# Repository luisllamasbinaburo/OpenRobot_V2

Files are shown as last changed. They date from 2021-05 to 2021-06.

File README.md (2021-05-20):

# OpenRobot v2

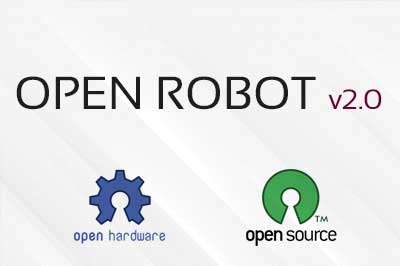
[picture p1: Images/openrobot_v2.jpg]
header


OpenRobot v2 is an Open Hardware PCB based on Arduino Nano, especially designed for teaching technology

Once assembled, you can use make multiple projects and robots without welding, just adding or removing components in the dupont headers.

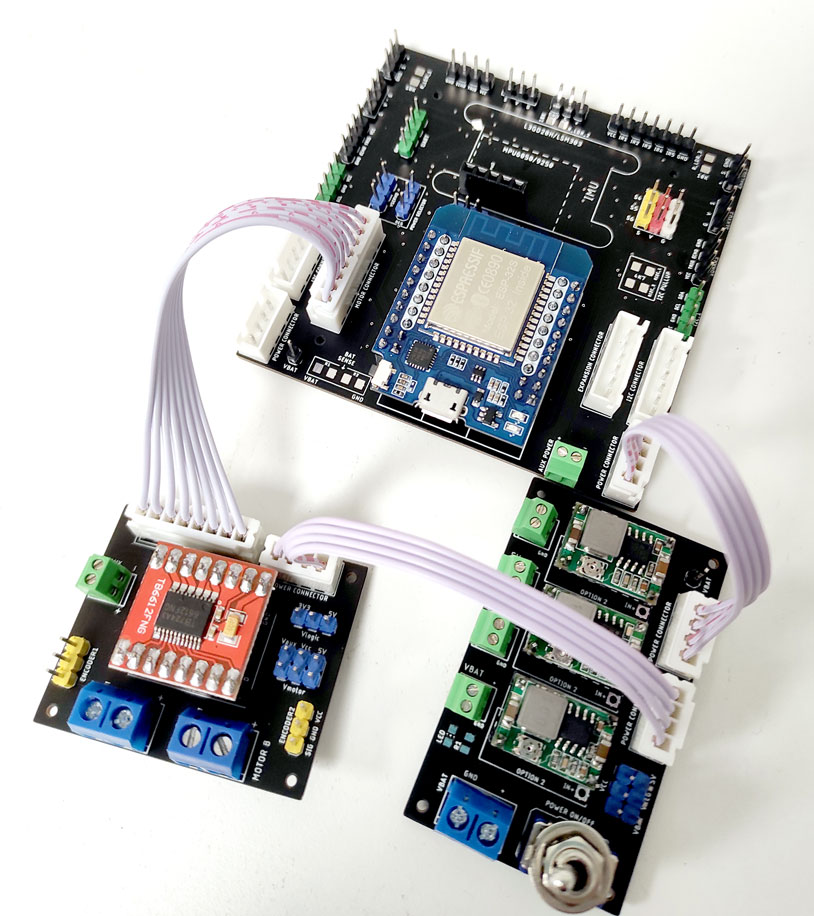
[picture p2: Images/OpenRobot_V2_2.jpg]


OpenRobot v2 is based on a modular design. Just select your main MCU module (Arduino Nano, ESP32, M5Stack...), and the module your project needs (Motors, GPIOs expansion...). Check the Wiki for information about each module.

## What can I make with OpenRobot v2?
Almost any DIY project you can ever imagine! 

Some of them,
- DC Motors Robot, like obstacle avoider (ultrasonic or Sharp), line follower, self-balancing bot...
- Servo Motor Robot, like 2-DOF Tower, 6-DOF Arms...
- Mosfet output for high current proyects (LED, electromagnets, water pumps)
- Bluetooth projects (HC-05/HC-06), like Android or PC communication, beacons...
- WiFi projects (ESP01), like controlling from Web, MQTT datalogger...
- Temperature, pressure, humidity weather station with BME280
- Any other project, thanks to the multiple available outputs!

## Modules
More info about each module in Wiki

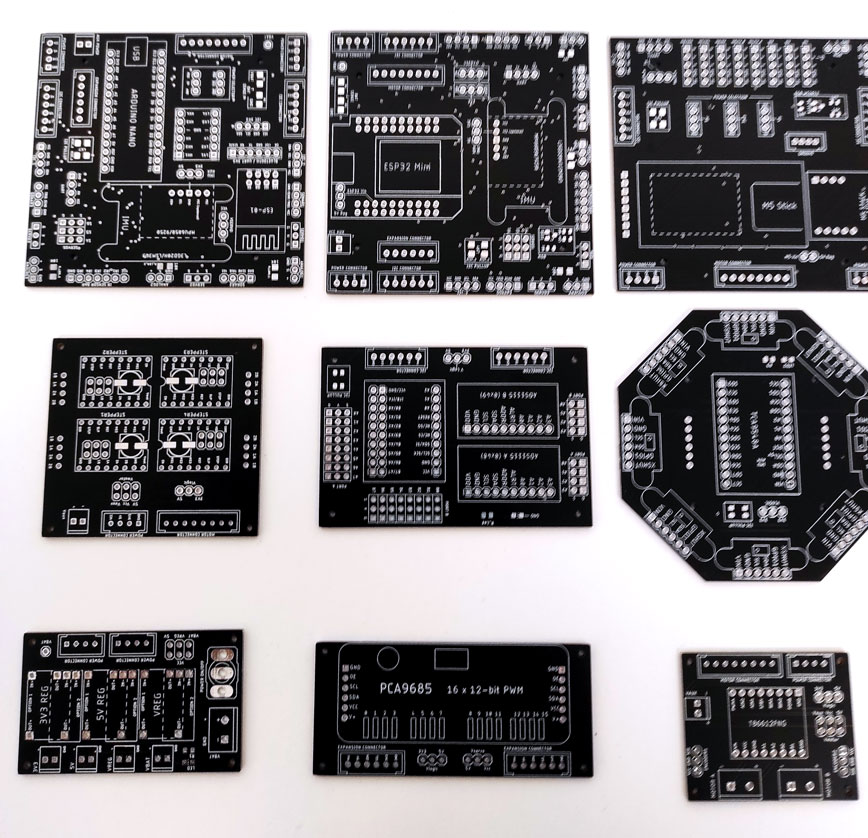
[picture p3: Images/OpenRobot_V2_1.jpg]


#### PowerSource
- DC Converter ([Wiki link](https://github.com/luisllamasbinaburo/OpenRobot_V2/wiki/Module_PowerSource))

#### MCUs
- Arduino Nano ([Wiki link](https://github.com/luisllamasbinaburo/OpenRobot_V2/wiki/Module_MCU_ArduinoNano))
- ESP32 Embed ([Wiki link](https://github.com/luisllamasbinaburo/OpenRobot_V2/wiki/Module_MCU_ESP32Embed))
- M5StickC / M5Stack Atom ([Wiki link](https://github.com/luisllamasbinaburo/OpenRobot_V2/wiki/Module_MCU_M5Stack))

#### Motors
- DC Motors ([Wiki link](https://github.com/luisllamasbinaburo/OpenRobot_V2/wiki/Module_Motor_DC))
- Steppers ([Wiki link](https://github.com/luisllamasbinaburo/OpenRobot_V2/wiki/Module_Motor_Stepper))
- I2C Servos ([Wiki link](https://github.com/luisllamasbinaburo/OpenRobot_V2/wiki/Module_I2C_Servo))

#### Expansions
- I2C GPIO ([Wiki link](https://github.com/luisllamasbinaburo/OpenRobot_V2/wiki/Module_I2C_GPIO))
- I2C TOF ([Wiki link](https://github.com/luisllamasbinaburo/OpenRobot_V2/wiki/Module_I2C_TOF))
- Mosfet ([Wiki link](https://github.com/luisllamasbinaburo/OpenRobot_V2/wiki/Module_Expansion_Mosfet))

## TODO:
- Improve documentation
- Improve code source / utilities (libraries, examples...)

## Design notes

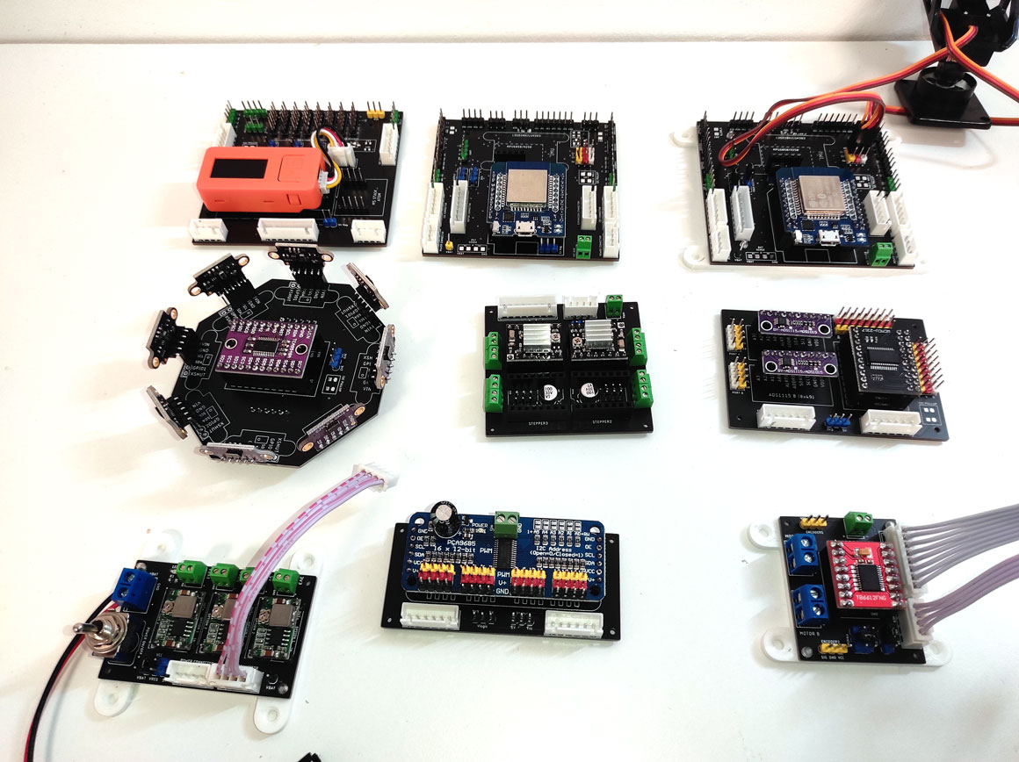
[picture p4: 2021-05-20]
Images/OpenRobot_V2_3.jpg

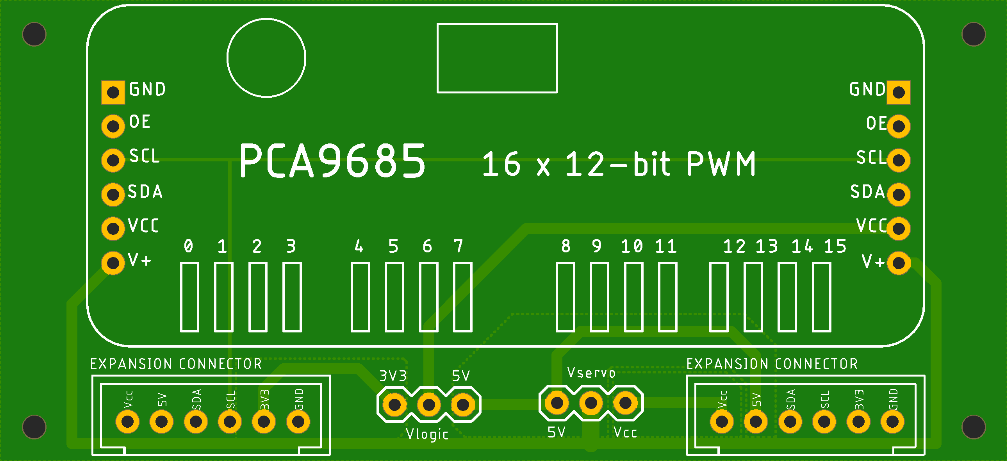
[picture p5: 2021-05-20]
Module_I2C_Servo/Module_I2C_Servo.png

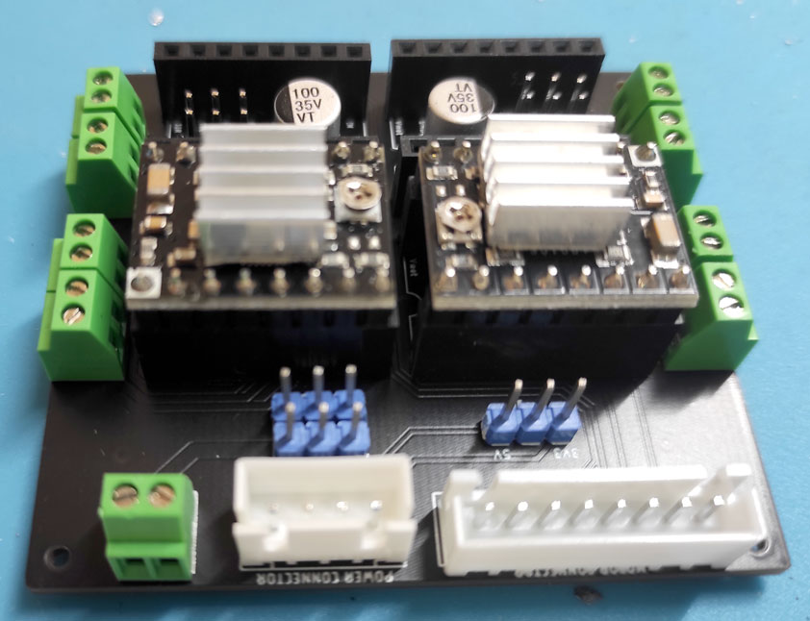
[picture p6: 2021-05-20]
Module_Motor_Stepper/Module_Motor_Stepper.jpg

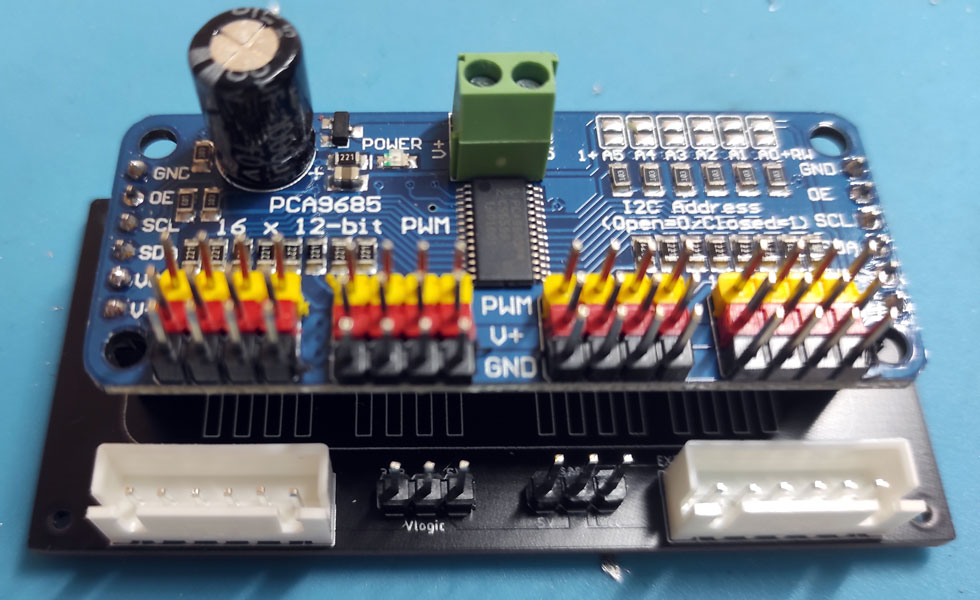
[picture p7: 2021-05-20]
Module_I2C_Servo/Module_I2C_Servo.jpg

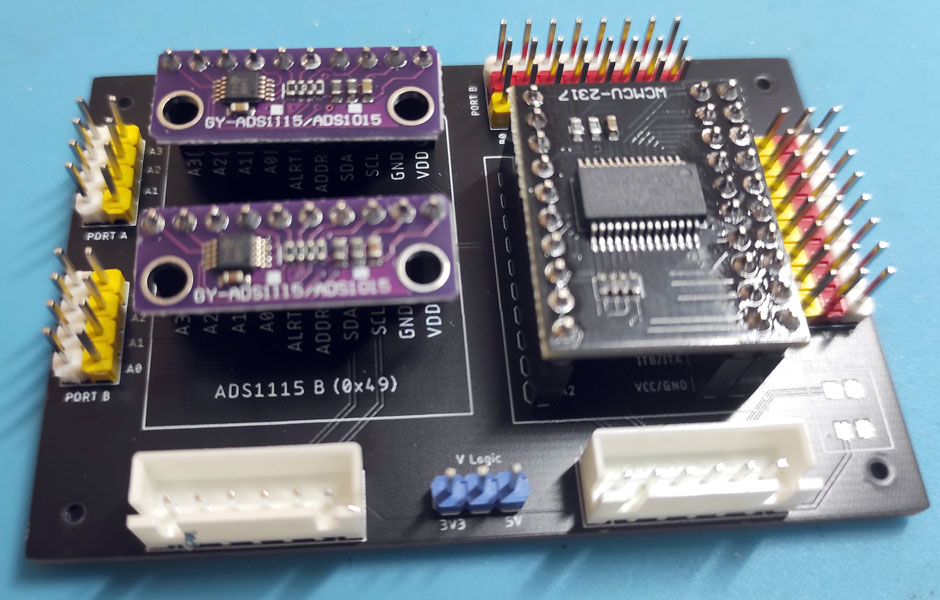
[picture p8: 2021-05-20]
Module_I2C_GPIO/Module_I2C_GPIO.jpg

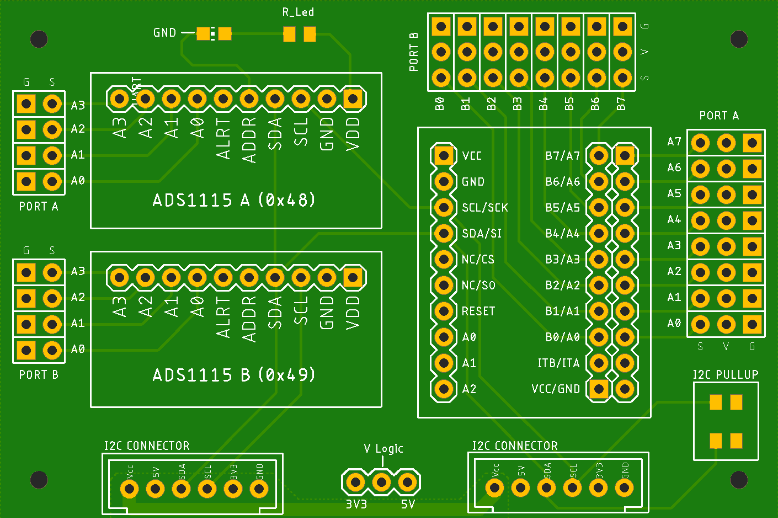
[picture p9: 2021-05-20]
Module_I2C_GPIO/Module_I2C_GPIO.png

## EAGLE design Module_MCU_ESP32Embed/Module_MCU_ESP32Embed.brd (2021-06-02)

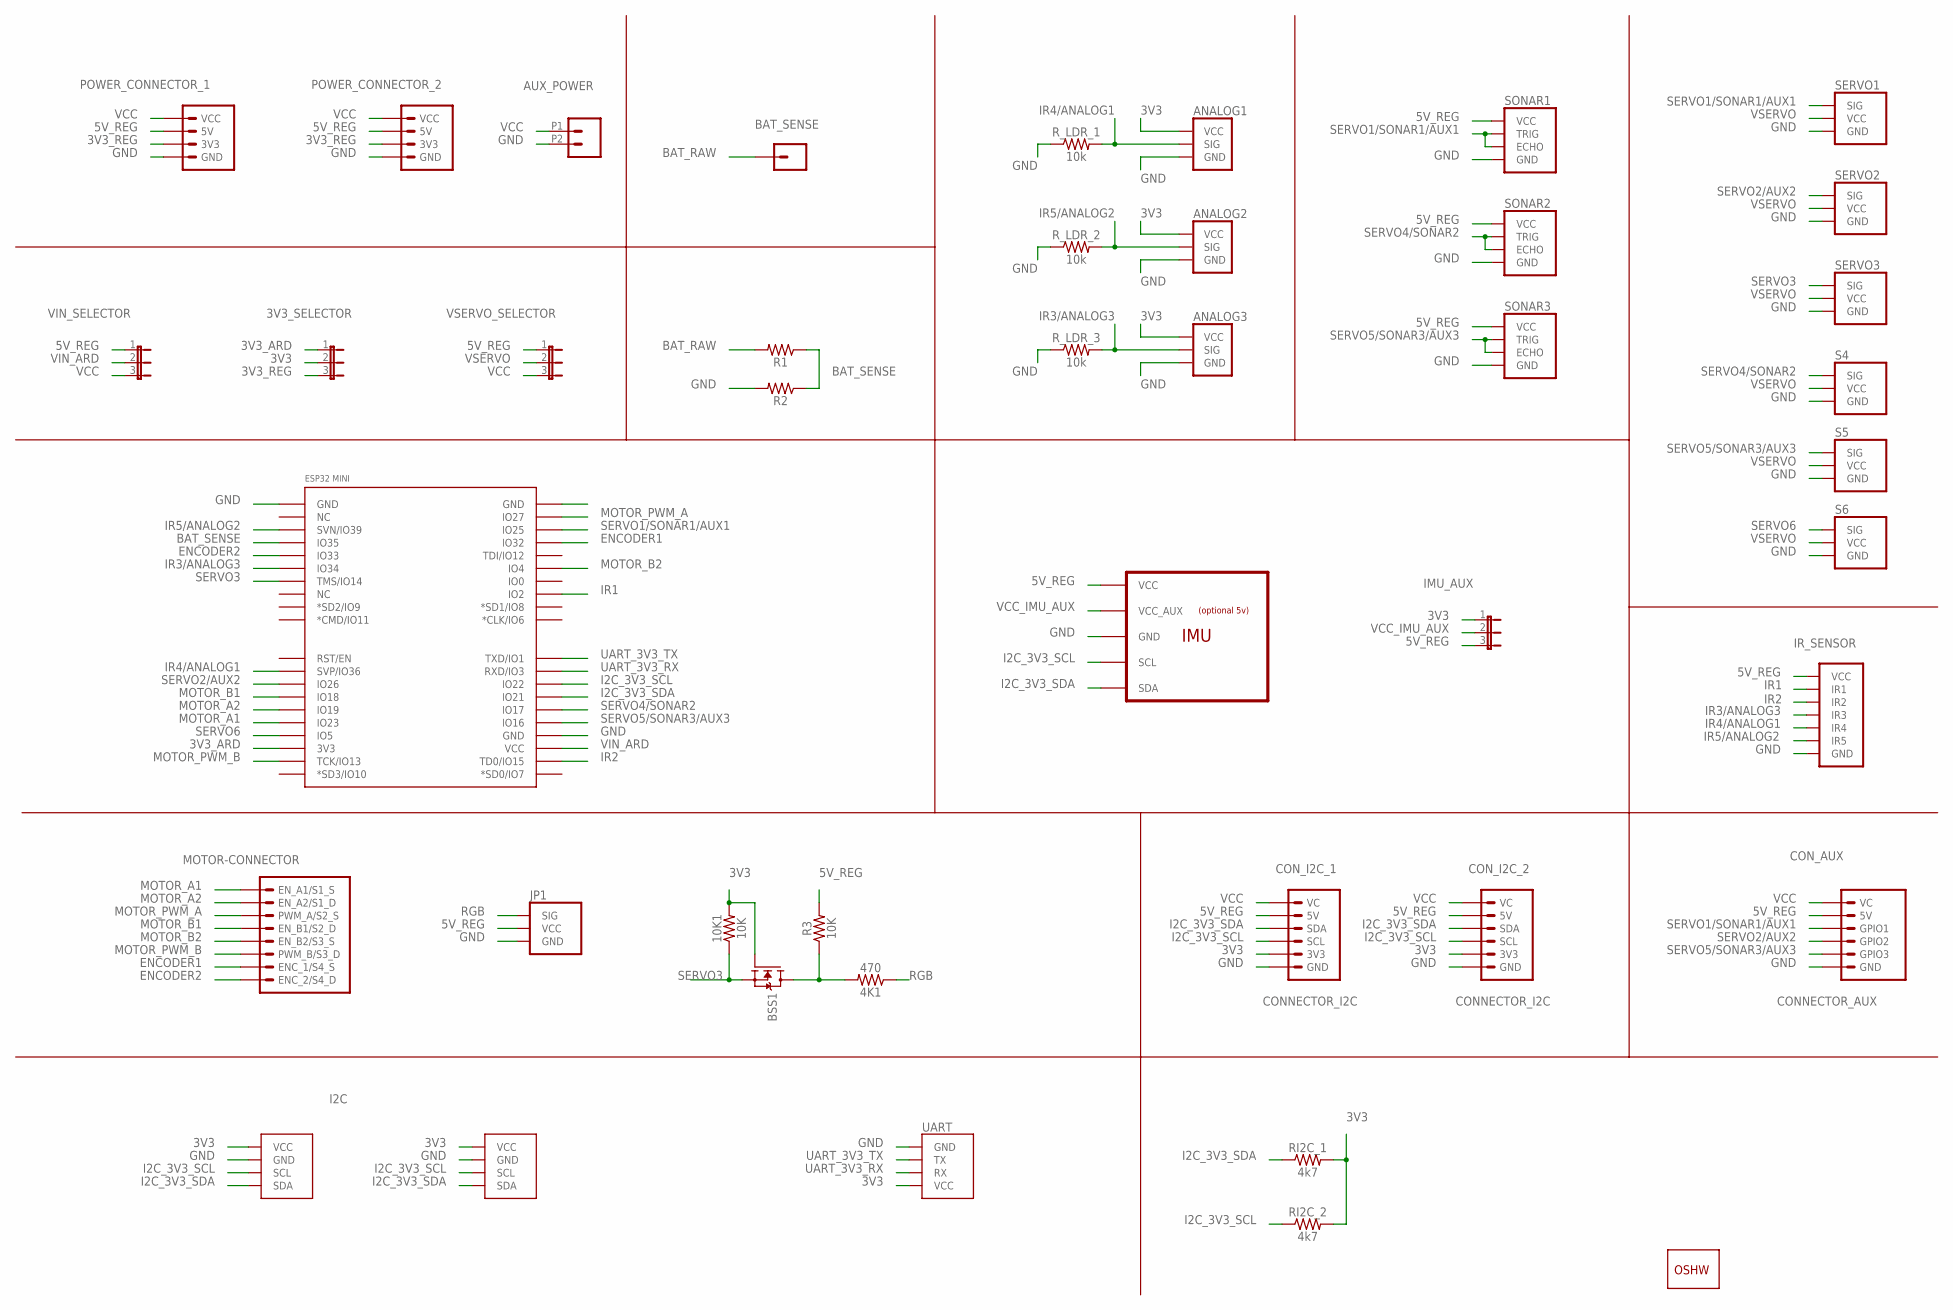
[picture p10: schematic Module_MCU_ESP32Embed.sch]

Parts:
3V3_SELECTOR: JUMPER_3
4K1: 470; 0805
10K1: 10K; 0805
ANALOG1, ANALOG2, ANALOG3: LDR/OCT; LDR
AUX_POWER: CONN_022.54MM_SCREWTERM; 1X02_2.54_SCREWTERM
BAT_SENSE: CONN_01; 1X01
BSS1: MOSFET-N-SOT23; SOT23
CON_AUX: CONNECTOR_AUX
CON_I2C_1, CON_I2C_2: CONNECTOR_I2C
GOLD_ORB_SM1: OSHWLOGO_GOLD_ORB_MED; OSHW1
I2C_1: I2C; I2C_VCC_GND_SCL_SDA
I2C_2: GENERIC_I2CVCC_GND_SCL_SDA; I2C_VCC_GND_SCL_SDA
IMU_AUX: JUMPER_3
IR_SENSOR: IR-5/OCT; IR-5
JP1: SERVOSERVO; SERVO
MOTOR_CONNECTOR: MOTOR-CONNECTOR
POWER_CONNECTOR_1, POWER_CONNECTOR_2: POWER-CONNECTOR
R1, R2: 1206
R3: 10K; 0805
RI2C_1, RI2C_2: 4k7; 1206
R_LDR_1, R_LDR_2, R_LDR_3: 10k; 1206
S4, S5, S6: SERVOSERVO; SERVO
SERVO1, SERVO2, SERVO3: SERVOSERVO; SERVO
SONAR1, SONAR2, SONAR3: ULTRASONIC/OCT; ULTRASONIC
U1: IMU_6/9/10DOFMPU6050; IMU_6/9/10DOF
U$5: ESP32-WEMOS
UART: UART; GENERIC_UART
VIN_SELECTOR: JUMPER_3
VSERVO_SELECTOR: JUMPER_3

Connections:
3V3: 3V3_SELECTOR.2, 10K1.2, ANALOG1.VCC, ANALOG2.VCC, ANALOG3.VCC, BSS1.1 (G), CON_I2C_1.3V3, CON_I2C_2.3V3, I2C_1.VCC, I2C_2.VCC, IMU_AUX.1, RI2C_1.2, RI2C_2.2, UART.VCC
3V3_ARD: 3V3_SELECTOR.1, U$5.3V3
3V3_REG: 3V3_SELECTOR.3, POWER_CONNECTOR_1.3V3, POWER_CONNECTOR_2.3V3
5V_REG: CON_AUX.5V, CON_I2C_1.5V, CON_I2C_2.5V, IMU_AUX.3, IR_SENSOR.VCC, JP1.VCC, POWER_CONNECTOR_1.5V, POWER_CONNECTOR_2.5V, R3.2, SONAR1.VCC, SONAR2.VCC, SONAR3.VCC, U1.VCC, VIN_SELECTOR.1, VSERVO_SELECTOR.1
BAT_RAW: BAT_SENSE.1, R1.2
BAT_SENSE: R1.1, R2.1, U$5.IO35
ENCODER1: MOTOR_CONNECTOR.ENC_1/S4_S, U$5.IO32
ENCODER2: MOTOR_CONNECTOR.ENC_2/S4_D, U$5.IO33
GND: ANALOG1.GND, ANALOG2.GND, ANALOG3.GND, AUX_POWER.P2 (2), CON_AUX.GND, CON_I2C_1.GND, CON_I2C_2.GND, I2C_1.GND, I2C_2.GND, IR_SENSOR.GND, JP1.GND, POWER_CONNECTOR_1.GND, POWER_CONNECTOR_2.GND, R2.2, R_LDR_1.1, R_LDR_2.1, R_LDR_3.1, S4.GND, S5.GND, S6.GND, SERVO1.GND, SERVO2.GND, SERVO3.GND, SONAR1.GND, SONAR2.GND, SONAR3.GND, U1.GND, U$5.GND@1 (GND), U$5.GND@3 (GND), UART.GND
I2C_3V3_SCL: CON_I2C_1.SCL, CON_I2C_2.SCL, I2C_1.SCL, I2C_2.SCL, RI2C_2.1, U1.SCL, U$5.IO22
I2C_3V3_SDA: CON_I2C_1.SDA, CON_I2C_2.SDA, I2C_1.SDA, I2C_2.SDA, RI2C_1.1, U1.SDA, U$5.IO21
IR1: IR_SENSOR.1 (IR1), U$5.IO2
IR2: IR_SENSOR.2 (IR2), U$5.TD0/IO15
IR3/ANALOG3: ANALOG3.SIG, IR_SENSOR.3 (IR3), R_LDR_3.2, U$5.IO34
IR4/ANALOG1: ANALOG1.SIG, IR_SENSOR.4 (IR4), R_LDR_1.2, U$5.SVP/IO36
IR5/ANALOG2: ANALOG2.SIG, IR_SENSOR.5 (IR5), R_LDR_2.2, U$5.SVN/IO39
MOTOR_A1: MOTOR_CONNECTOR.EN_A1/S1_S, U$5.IO23
MOTOR_A2: MOTOR_CONNECTOR.EN_A2/S1_D, U$5.IO19
MOTOR_B1: MOTOR_CONNECTOR.EN_B1/S2_D, U$5.IO18
MOTOR_B2: MOTOR_CONNECTOR.EN_B2/S3_S, U$5.IO4
MOTOR_PWM_A: MOTOR_CONNECTOR.PWM_A/S2_S, U$5.IO27
MOTOR_PWM_B: MOTOR_CONNECTOR.PWM_B/S3_D, U$5.TCK/IO13
unnamed: 4K1.2, BSS1.3 (D), R3.1
RGB: 4K1.1, JP1.SIG
SERVO1/SONAR1/AUX1: CON_AUX.GPIO1, SERVO1.SIG, SONAR1.ECHO, SONAR1.TRIG, U$5.IO25
SERVO2/AUX2: CON_AUX.GPIO2, SERVO2.SIG, U$5.IO26
SERVO3: 10K1.1, BSS1.2 (S), SERVO3.SIG, U$5.TMS/IO14
SERVO4/SONAR2: S4.SIG, SONAR2.ECHO, SONAR2.TRIG, U$5.IO17
SERVO5/SONAR3/AUX3: CON_AUX.GPIO3, S5.SIG, SONAR3.ECHO, SONAR3.TRIG, U$5.IO16
SERVO6: S6.SIG, U$5.IO5
UART_3V3_RX: U$5.RXD/IO3, UART.RX
UART_3V3_TX: U$5.TXD/IO1, UART.TX
VCC: AUX_POWER.P1 (1), CON_AUX.VC, CON_I2C_1.VC, CON_I2C_2.VC, POWER_CONNECTOR_1.VCC, POWER_CONNECTOR_2.VCC, VIN_SELECTOR.3, VSERVO_SELECTOR.3
VCC_IMU_AUX: IMU_AUX.2, U1.VCC_AUX
VIN_ARD: U$5.VCC, VIN_SELECTOR.2
VSERVO: S4.VCC, S5.VCC, S6.VCC, SERVO1.VCC, SERVO2.VCC, SERVO3.VCC, VSERVO_SELECTOR.2

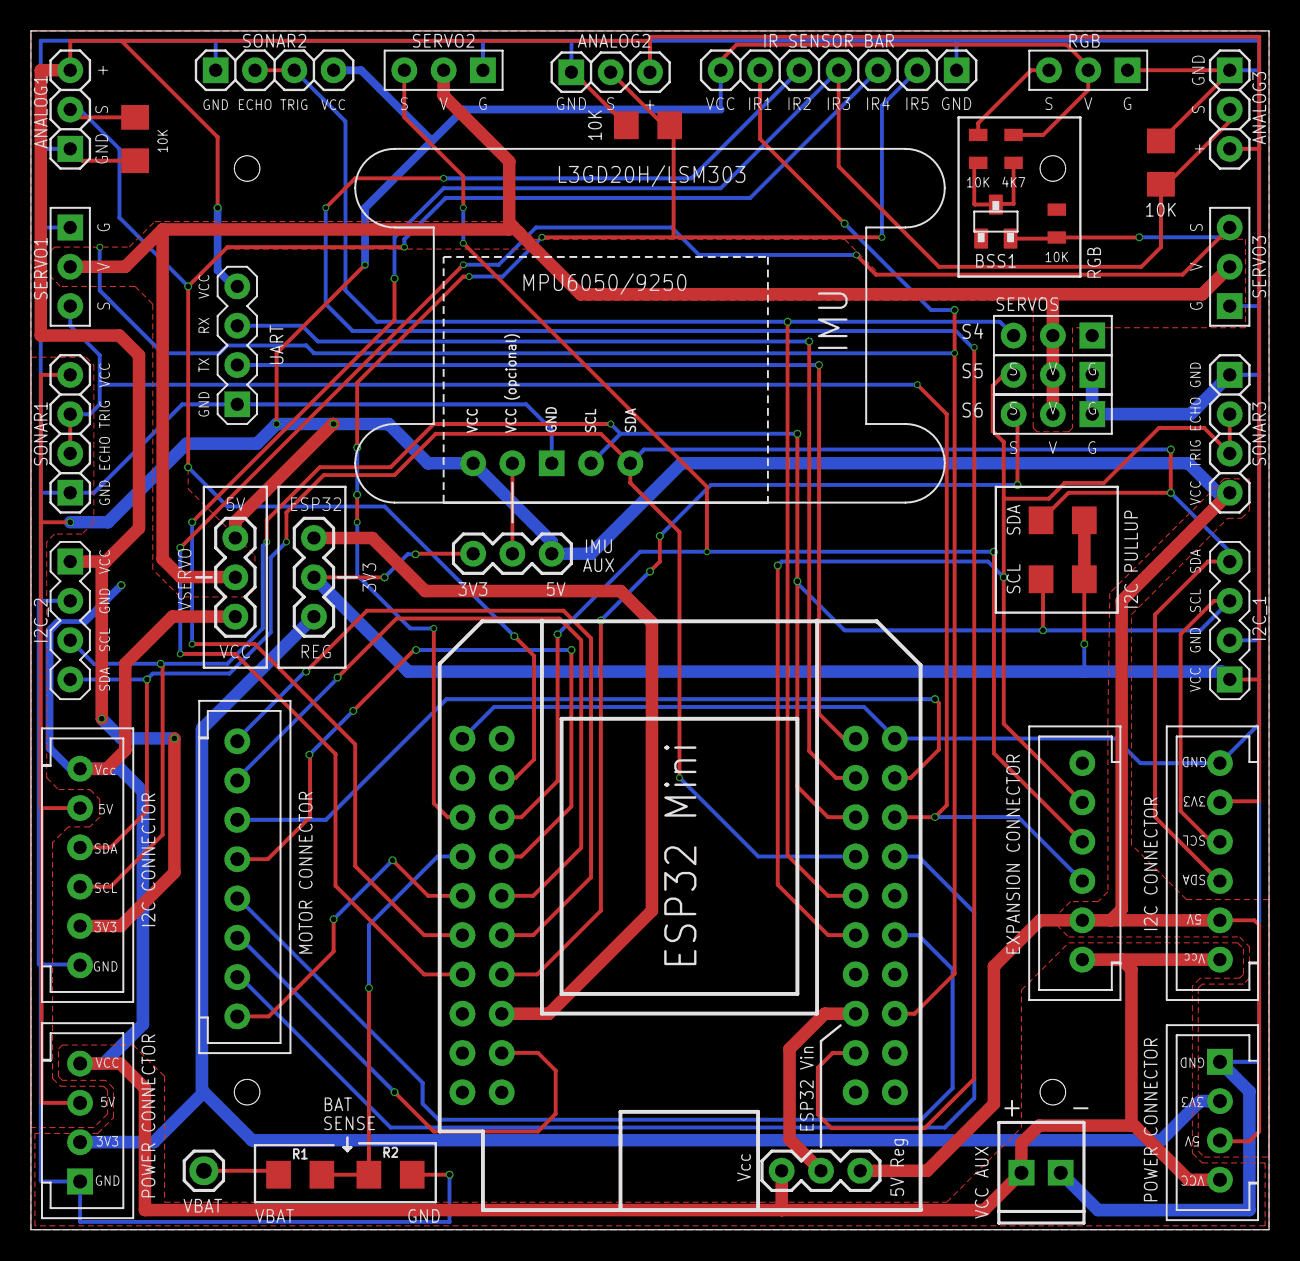
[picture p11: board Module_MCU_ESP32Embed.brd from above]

Board: 2 copper layers, 80.0 x 77.5 mm, 43 parts (1 on the bottom side), 36 nets.

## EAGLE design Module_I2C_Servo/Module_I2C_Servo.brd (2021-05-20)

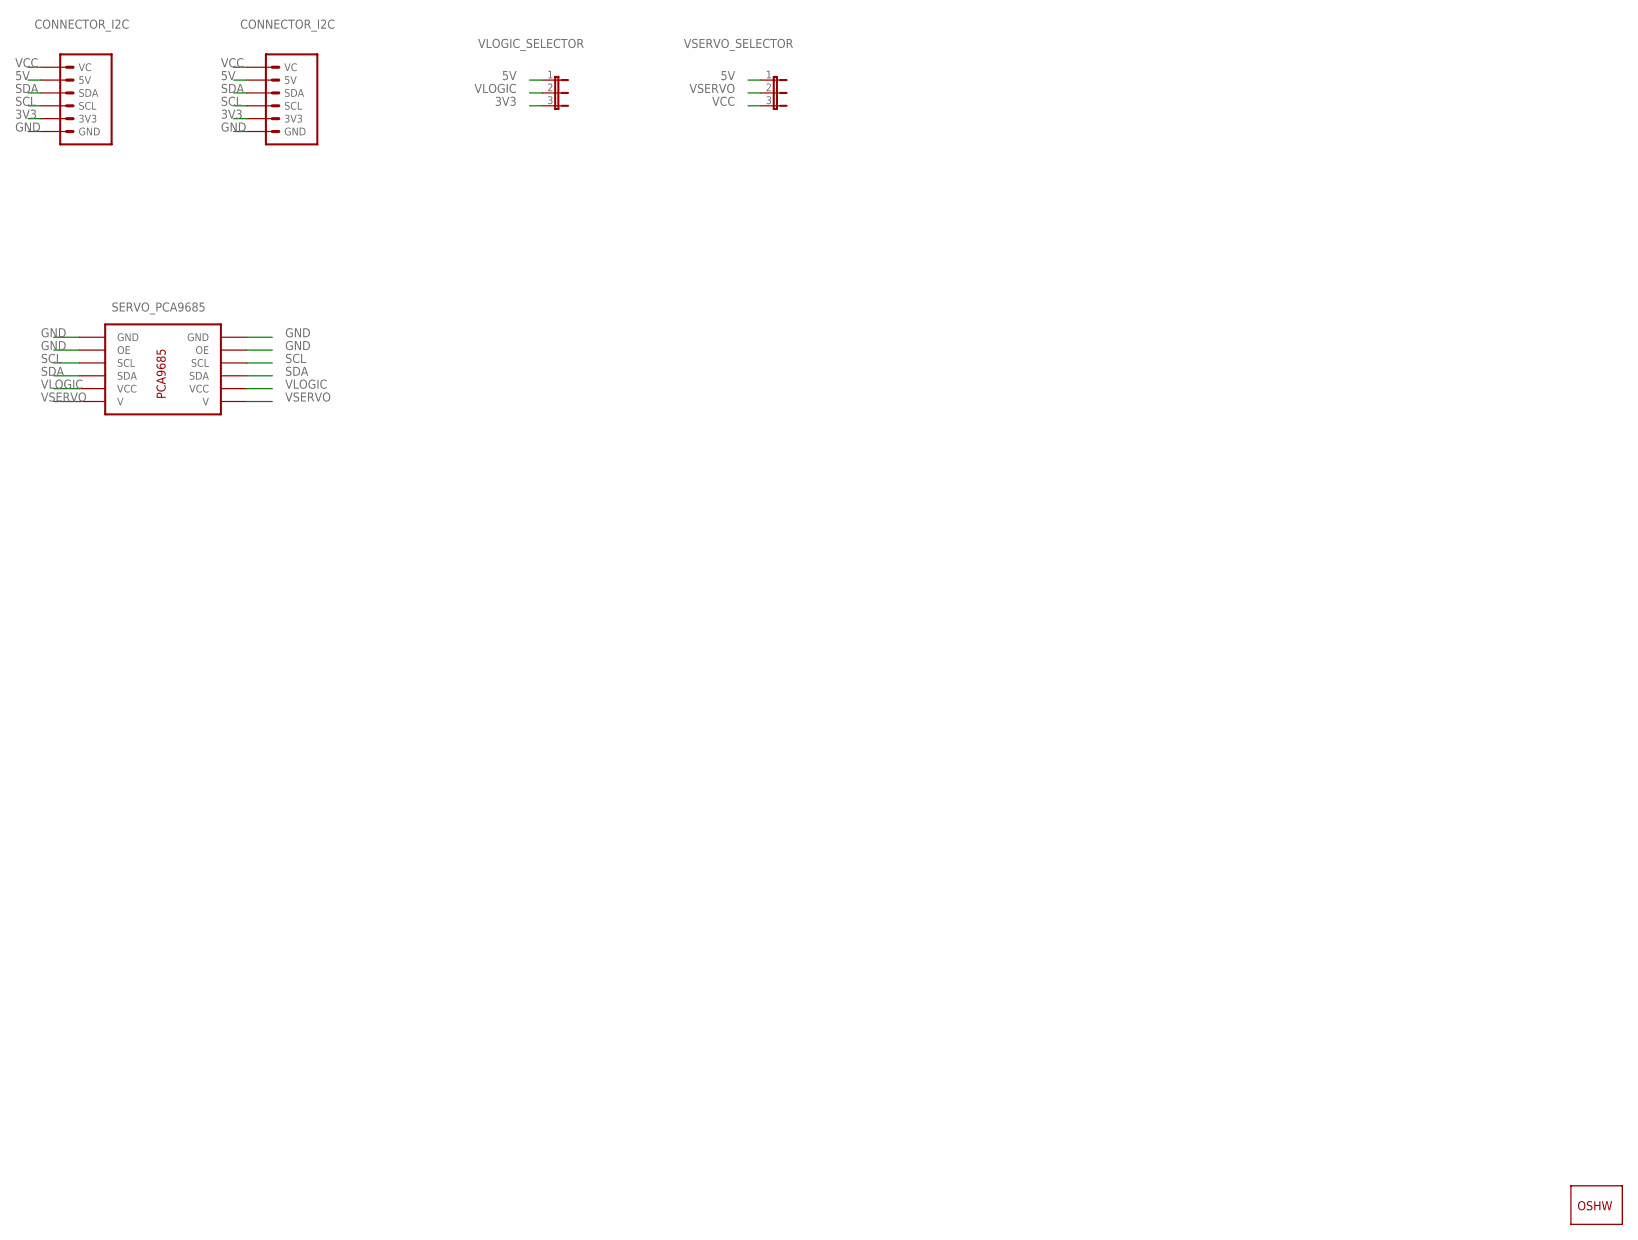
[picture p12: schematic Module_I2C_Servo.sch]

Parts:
GOLD_ORB_SM1: OSHWLOGO_GOLD_ORB_MED; OSHW1
U$2: SERVO_PCA9685
U$3, U$4: CONNECTOR_I2C
VLOGIC_SELECTOR: JUMPER_3
VSERVO_SELECTOR: JUMPER_3

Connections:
3V3: U$3.3V3, U$4.3V3, VLOGIC_SELECTOR.3
5V: U$3.5V, U$4.5V, VLOGIC_SELECTOR.1, VSERVO_SELECTOR.1
GND: U$2.GND@0 (GND), U$2.GND@1 (GND), U$2.OE@0 (OE), U$2.OE@1 (OE), U$3.GND, U$4.GND
SCL: U$2.SCL@0 (SCL), U$2.SCL@1 (SCL), U$3.SCL, U$4.SCL
SDA: U$2.SDA@0 (SDA), U$2.SDA@1 (SDA), U$3.SDA, U$4.SDA
VCC: U$3.VC, U$4.VC, VSERVO_SELECTOR.3
VLOGIC: U$2.VCC@0 (VCC), U$2.VCC@1 (VCC), VLOGIC_SELECTOR.2
VSERVO: U$2.VSERVO@0 (V), U$2.VSERVO@1 (V), VSERVO_SELECTOR.2

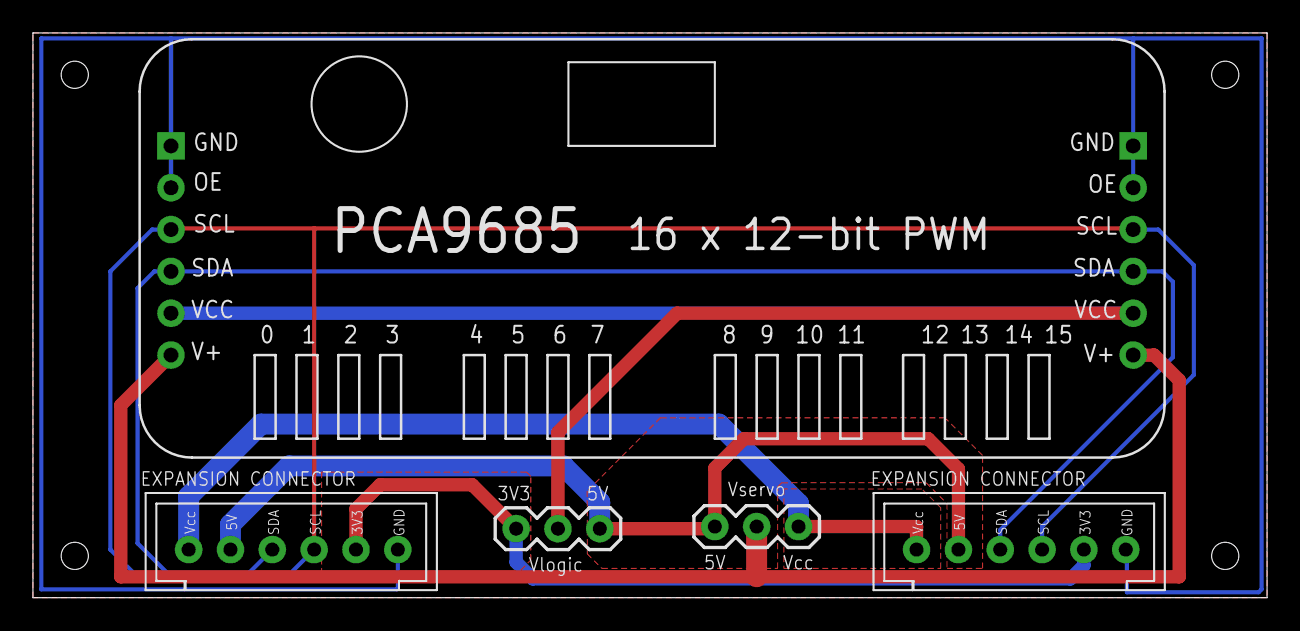
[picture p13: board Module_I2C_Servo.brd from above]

Board: 2 copper layers, 74.9 x 34.3 mm, 6 parts (1 on the bottom side), 8 nets.

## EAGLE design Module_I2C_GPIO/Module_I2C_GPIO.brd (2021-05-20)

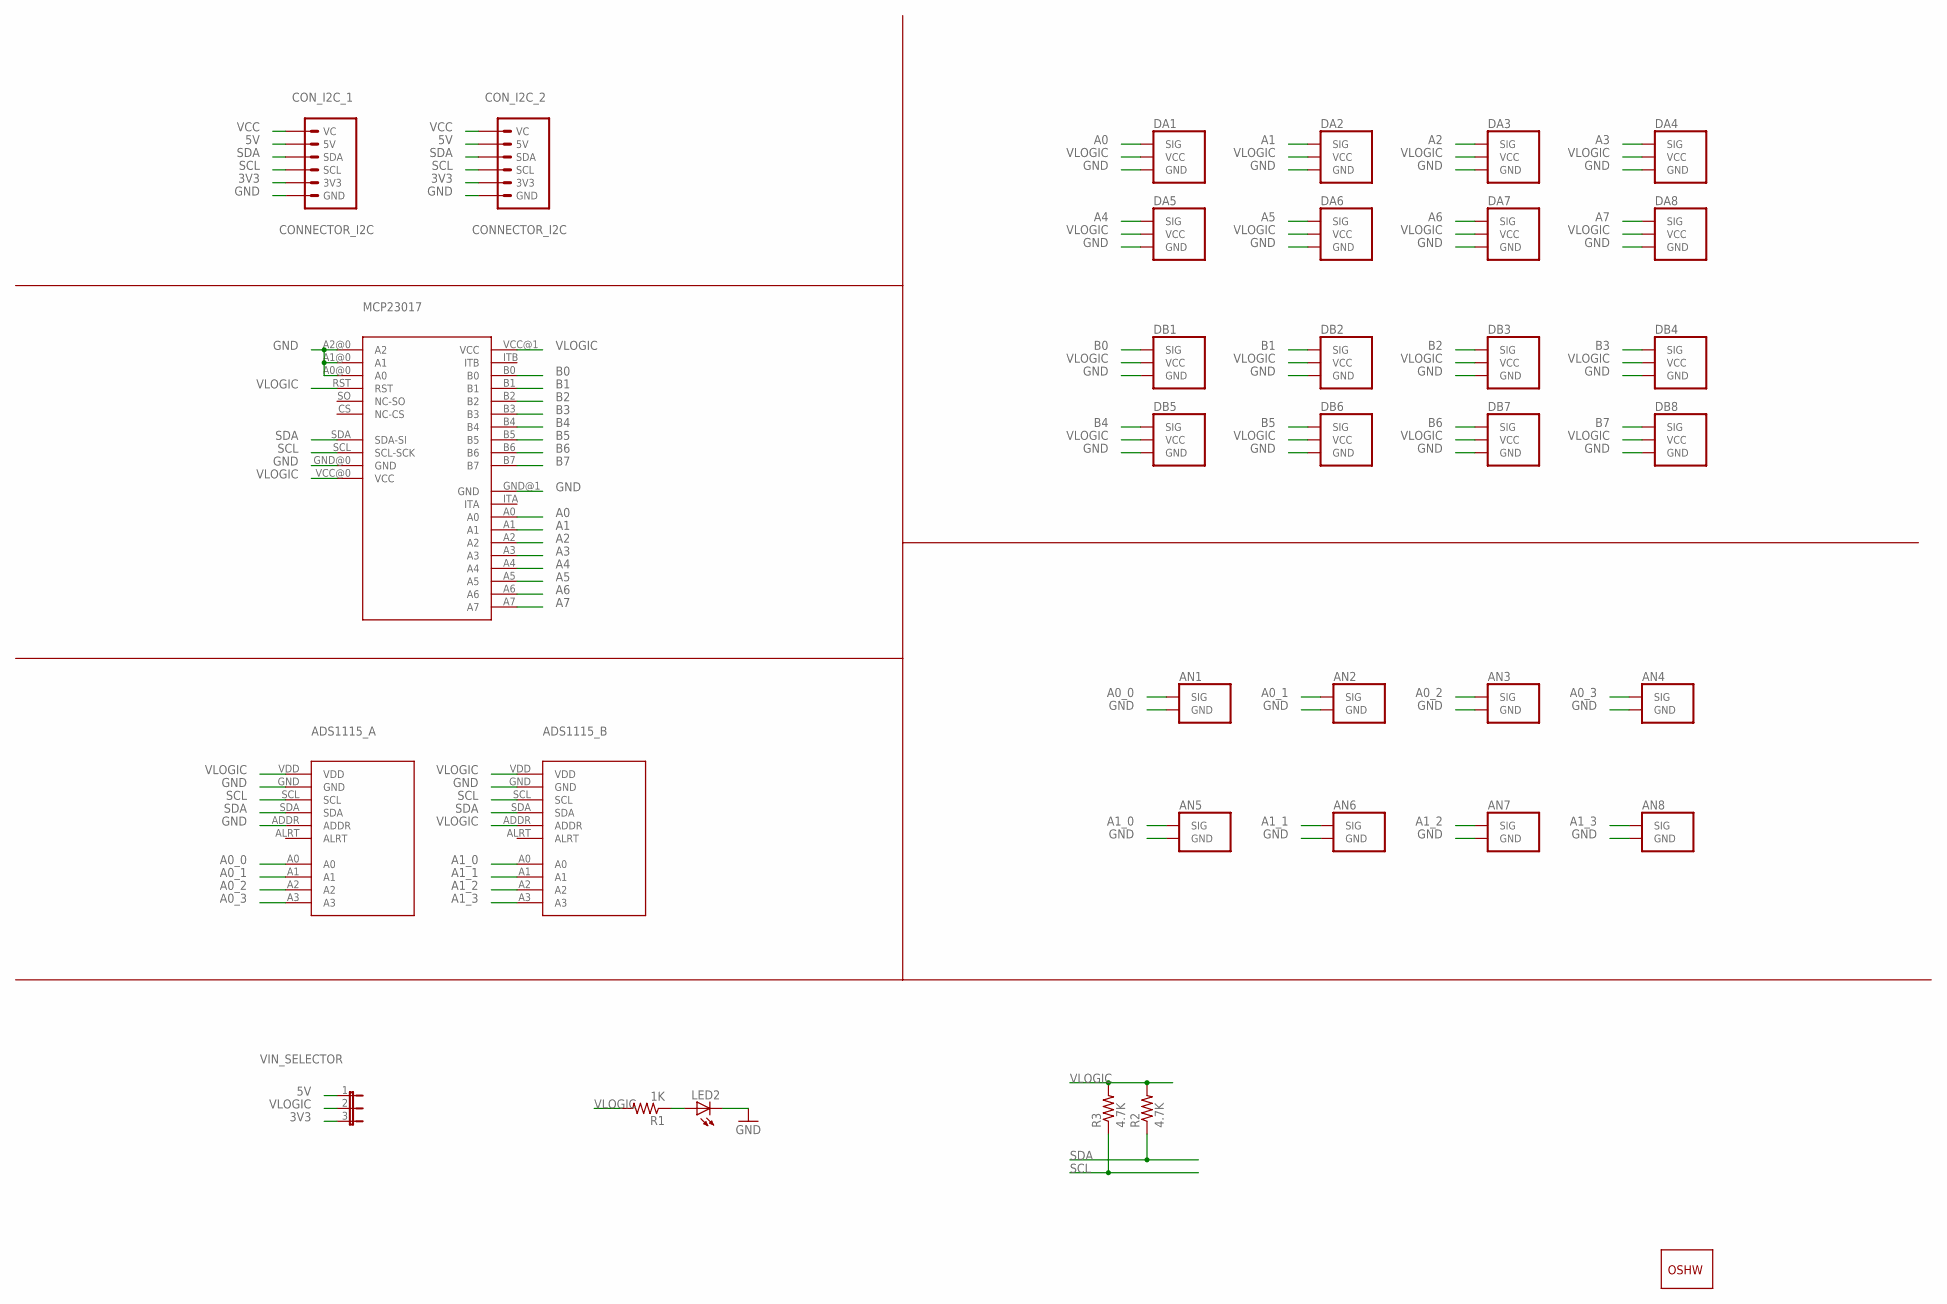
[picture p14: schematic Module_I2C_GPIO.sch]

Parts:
ADS1115_A, ADS1115_B: ADC-4CH-ADS1115
AN1, AN2, AN3, AN4, AN5, AN6, AN7, AN8: SERVO_2
CON_I2C_1, CON_I2C_2: CONNECTOR_I2C
DA1, DA2, DA3, DA4, DA5, DA6, DA7, DA8: SERVOSERVO; SERVO
DB1, DB2, DB3, DB4, DB5, DB6, DB7, DB8: SERVOSERVO; SERVO
GOLD_ORB_SM1: OSHWLOGO_GOLD_ORB_MED; OSHW1
LED2: LEDCHIP-LED0805; CHIP-LED0805
MCP23017: GPIO-I2C-MCP23017
R1: 1K; R0805
R2, R3: 4.7K; R0805
VIN_SELECTOR: JUMPER_3

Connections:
3V3: CON_I2C_1.3V3, CON_I2C_2.3V3, VIN_SELECTOR.3
5V: CON_I2C_1.5V, CON_I2C_2.5V, VIN_SELECTOR.1
A0: DA1.SIG, MCP23017.A0
A0_0: ADS1115_A.A0, AN1.SIG
A0_1: ADS1115_A.A1, AN2.SIG
A0_2: ADS1115_A.A2, AN3.SIG
A0_3: ADS1115_A.A3, AN4.SIG
A1: DA2.SIG, MCP23017.A1
A1_0: ADS1115_B.A0, AN5.SIG
A1_1: ADS1115_B.A1, AN6.SIG
A1_2: ADS1115_B.A2, AN7.SIG
A1_3: ADS1115_B.A3, AN8.SIG
A2: DA3.SIG, MCP23017.A2
A3: DA4.SIG, MCP23017.A3
A4: DA5.SIG, MCP23017.A4
A5: DA6.SIG, MCP23017.A5
A6: DA7.SIG, MCP23017.A6
A7: DA8.SIG, MCP23017.A7
B0: DB1.SIG, MCP23017.B0
B1: DB2.SIG, MCP23017.B1
B2: DB3.SIG, MCP23017.B2
B3: DB4.SIG, MCP23017.B3
B4: DB5.SIG, MCP23017.B4
B5: DB6.SIG, MCP23017.B5
B6: DB7.SIG, MCP23017.B6
B7: DB8.SIG, MCP23017.B7
GND: ADS1115_A.ADDR, ADS1115_A.GND, ADS1115_B.GND, AN1.GND, AN2.GND, AN3.GND, AN4.GND, AN5.GND, AN6.GND, AN7.GND, AN8.GND, CON_I2C_1.GND, CON_I2C_2.GND, DA1.GND, DA2.GND, DA3.GND, DA4.GND, DA5.GND, DA6.GND, DA7.GND, DA8.GND, DB1.GND, DB2.GND, DB3.GND, DB4.GND, DB5.GND, DB6.GND, DB7.GND, DB8.GND, LED2.C, MCP23017.A0@0 (A0), MCP23017.A1@0 (A1), MCP23017.A2@0 (A2), MCP23017.GND@0 (GND), MCP23017.GND@1 (GND)
unnamed: LED2.A, R1.1
SCL: ADS1115_A.SCL, ADS1115_B.SCL, CON_I2C_1.SCL, CON_I2C_2.SCL, MCP23017.SCL (SCL-SCK), R3.1
SDA: ADS1115_A.SDA, ADS1115_B.SDA, CON_I2C_1.SDA, CON_I2C_2.SDA, MCP23017.SDA (SDA-SI), R2.1
VCC: CON_I2C_1.VC, CON_I2C_2.VC
VLOGIC: ADS1115_A.VDD, ADS1115_B.ADDR, ADS1115_B.VDD, DA1.VCC, DA2.VCC, DA3.VCC, DA4.VCC, DA5.VCC, DA6.VCC, DA7.VCC, DA8.VCC, DB1.VCC, DB2.VCC, DB3.VCC, DB4.VCC, DB5.VCC, DB6.VCC, DB7.VCC, DB8.VCC, MCP23017.RST, MCP23017.VCC@0 (VCC), MCP23017.VCC@1 (VCC), R1.2, R2.2, R3.2, VIN_SELECTOR.2

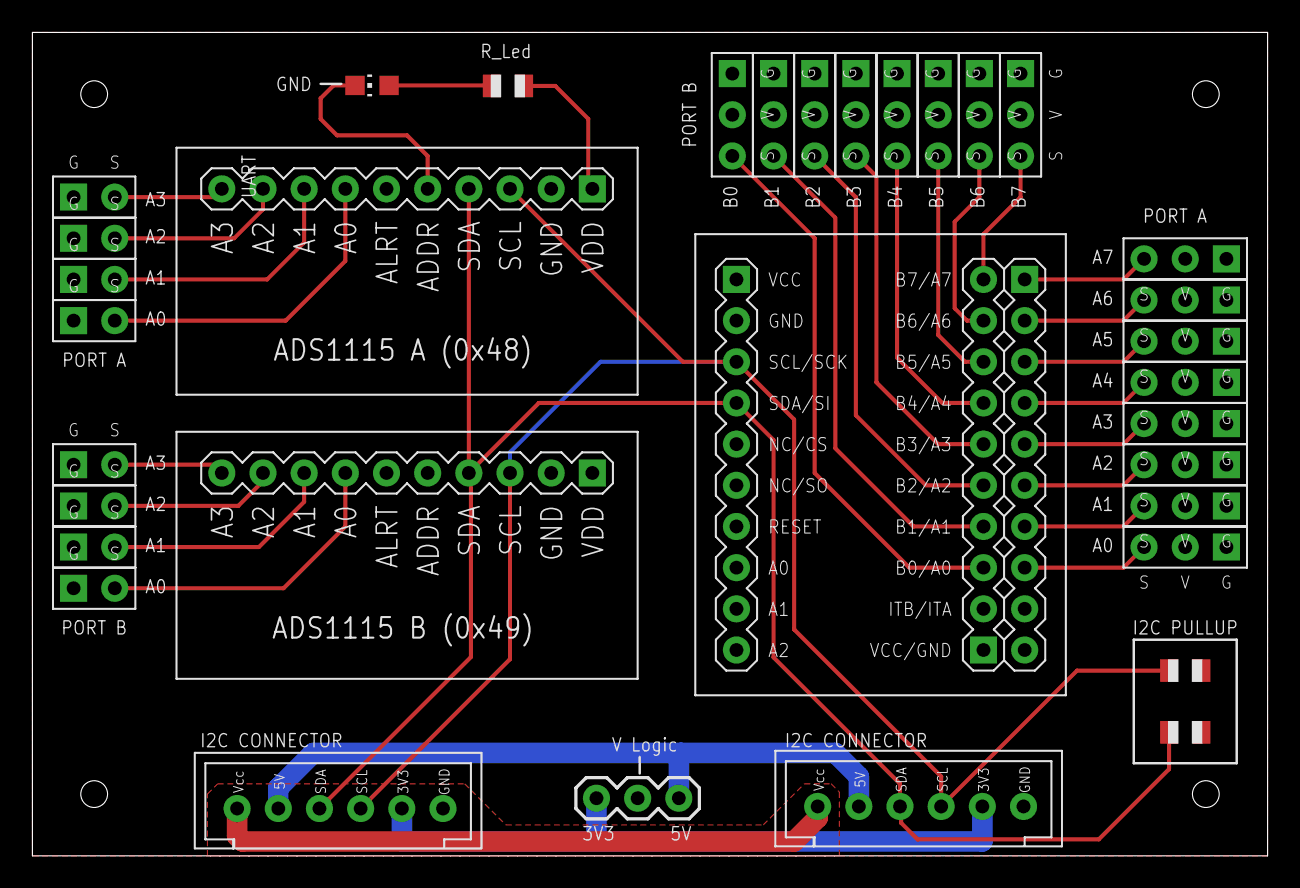
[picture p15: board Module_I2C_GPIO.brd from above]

Board: 2 copper layers, 76.2 x 50.8 mm, 35 parts (1 on the bottom side), 32 nets.

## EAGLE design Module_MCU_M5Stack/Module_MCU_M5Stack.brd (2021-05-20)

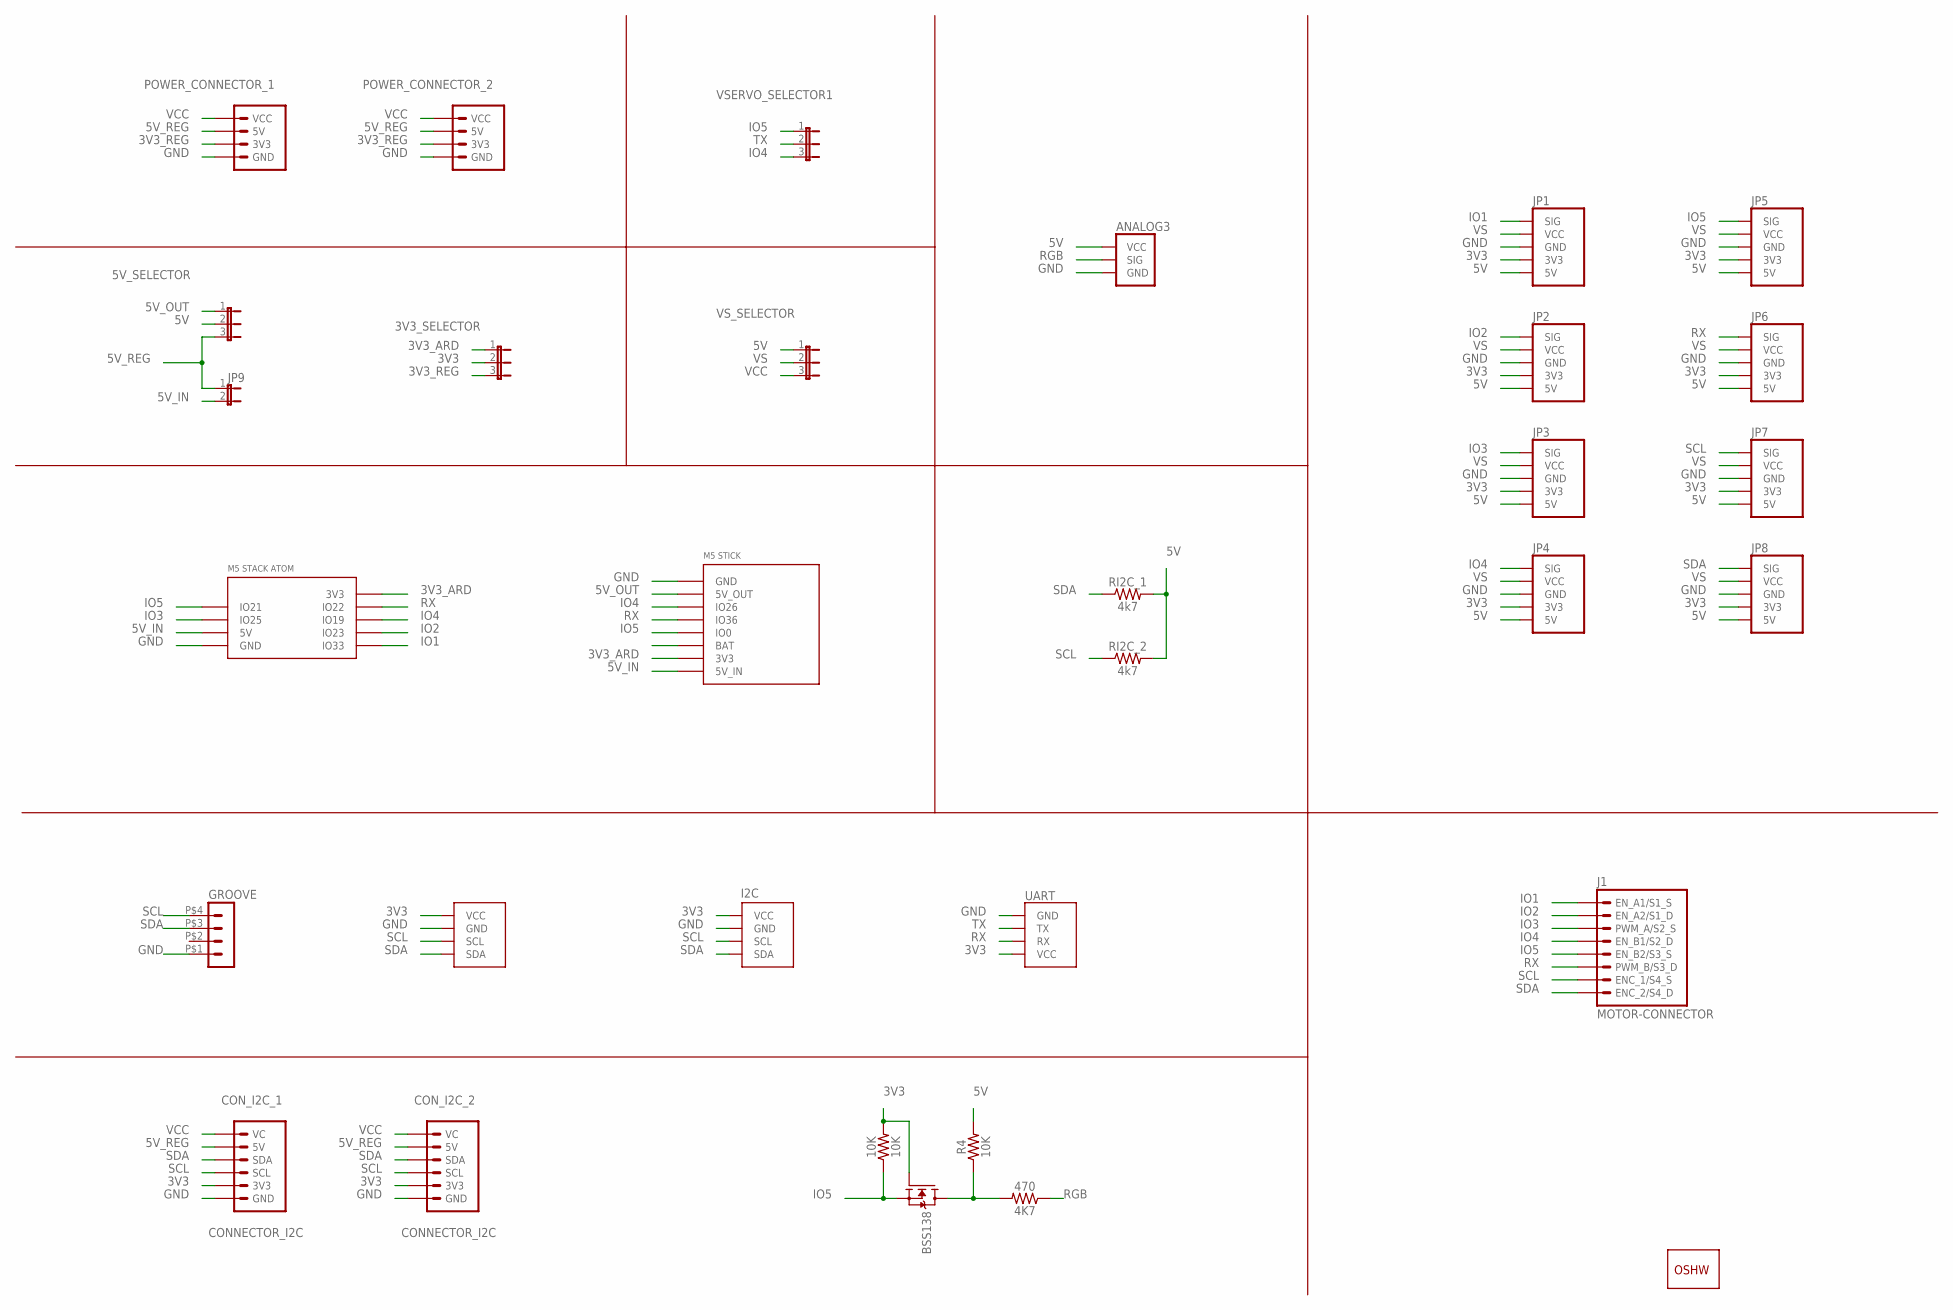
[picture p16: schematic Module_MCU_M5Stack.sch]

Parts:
3V3_SELECTOR, 5V_SELECTOR: JUMPER_3
4K7: 470; 0805
10K: 10K; 0805
ANALOG3: LDR/OCT; LDR
BSS138: MOSFET-N-SOT23; SOT23
CON_I2C_1, CON_I2C_2: CONNECTOR_I2C
GOLD_ORB_SM1: OSHWLOGO_GOLD_ORB_MED; OSHW1
GROOVE: GROOVE
I2C_1: I2C; I2C_VCC_GND_SCL_SDA
I2C_2: GENERIC_I2CVCC_GND_SCL_SDA; I2C_VCC_GND_SCL_SDA
J1: MOTOR-CONNECTOR
JP1, JP2, JP3, JP4, JP5, JP6, JP7, JP8: SERVO_5
JP9: JUMPER_2PTH; JUMPER_2
POWER_CONNECTOR_1, POWER_CONNECTOR_2: POWER-CONNECTOR
R4: 10K; 0805
RI2C_1, RI2C_2: 4k7; 1206
U$1: M5-STACK-ATOM
U$2: M5-STICK
UART: UART; GENERIC_UART
VSERVO_SELECTOR1: JUMPER_3
VS_SELECTOR: JUMPER_3

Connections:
3V3: 3V3_SELECTOR.2, 10K.2, BSS138.1 (G), CON_I2C_1.3V3, CON_I2C_2.3V3, I2C_1.VCC, I2C_2.VCC, JP1.3V3, JP2.3V3, JP3.3V3, JP4.3V3, JP5.3V3, JP6.3V3, JP7.3V3, JP8.3V3, UART.VCC
3V3_ARD: 3V3_SELECTOR.1, U$1.3V3, U$2.3V3
3V3_REG: 3V3_SELECTOR.3, POWER_CONNECTOR_1.3V3, POWER_CONNECTOR_2.3V3
5V: 5V_SELECTOR.2, ANALOG3.VCC, JP1.5V, JP2.5V, JP3.5V, JP4.5V, JP5.5V, JP6.5V, JP7.5V, JP8.5V, R4.2, RI2C_1.2, RI2C_2.2, VS_SELECTOR.1
5V_IN: JP9.2, U$1.5V, U$2.5V_IN
5V_OUT: 5V_SELECTOR.1, U$2.5V_OUT
5V_REG: 5V_SELECTOR.3, CON_I2C_1.5V, CON_I2C_2.5V, JP9.1, POWER_CONNECTOR_1.5V, POWER_CONNECTOR_2.5V
GND: ANALOG3.GND, CON_I2C_1.GND, CON_I2C_2.GND, GROOVE.P$1 (1), I2C_1.GND, I2C_2.GND, JP1.GND, JP2.GND, JP3.GND, JP4.GND, JP5.GND, JP6.GND, JP7.GND, JP8.GND, POWER_CONNECTOR_1.GND, POWER_CONNECTOR_2.GND, U$1.GND, U$2.GND, UART.GND
IO1: J1.EN_A1/S1_S, JP1.SIG, U$1.IO33
IO2: J1.EN_A2/S1_D, JP2.SIG, U$1.IO23
IO3: J1.PWM_A/S2_S, JP3.SIG, U$1.IO25
IO4: J1.EN_B1/S2_D, JP4.SIG, U$1.IO19, U$2.IO26, VSERVO_SELECTOR1.3
IO5: 10K.1, BSS138.2 (S), J1.EN_B2/S3_S, JP5.SIG, U$1.IO21, U$2.IO0, VSERVO_SELECTOR1.1
unnamed: 4K7.2, BSS138.3 (D), R4.1
RGB: 4K7.1, ANALOG3.SIG
RX: J1.PWM_B/S3_D, JP6.SIG, U$1.IO22, U$2.IO36, UART.RX
SCL: CON_I2C_1.SCL, CON_I2C_2.SCL, GROOVE.P$4 (4), I2C_1.SCL, I2C_2.SCL, J1.ENC_1/S4_S, JP7.SIG, RI2C_2.1
SDA: CON_I2C_1.SDA, CON_I2C_2.SDA, GROOVE.P$3 (3), I2C_1.SDA, I2C_2.SDA, J1.ENC_2/S4_D, JP8.SIG, RI2C_1.1
TX: UART.TX, VSERVO_SELECTOR1.2
VCC: CON_I2C_1.VC, CON_I2C_2.VC, POWER_CONNECTOR_1.VCC, POWER_CONNECTOR_2.VCC, VS_SELECTOR.3
VS: JP1.VCC, JP2.VCC, JP3.VCC, JP4.VCC, JP5.VCC, JP6.VCC, JP7.VCC, JP8.VCC, VS_SELECTOR.2

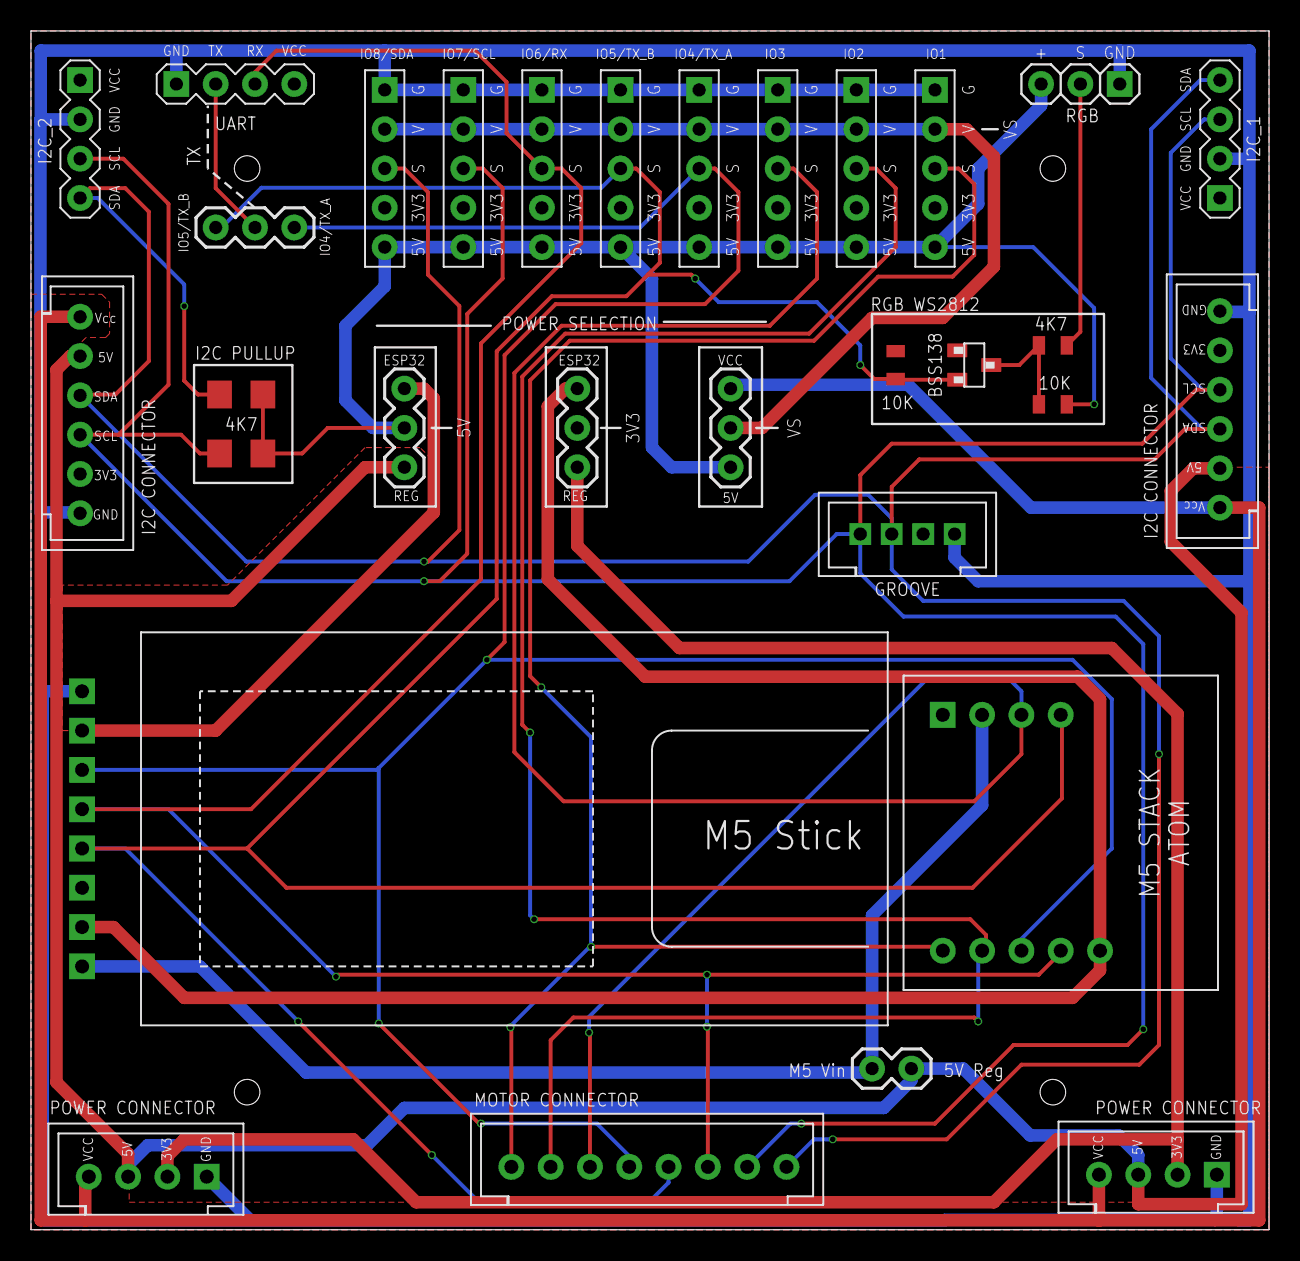
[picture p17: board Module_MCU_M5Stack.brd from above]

Board: 2 copper layers, 80.0 x 77.5 mm, 32 parts (1 on the bottom side), 21 nets.

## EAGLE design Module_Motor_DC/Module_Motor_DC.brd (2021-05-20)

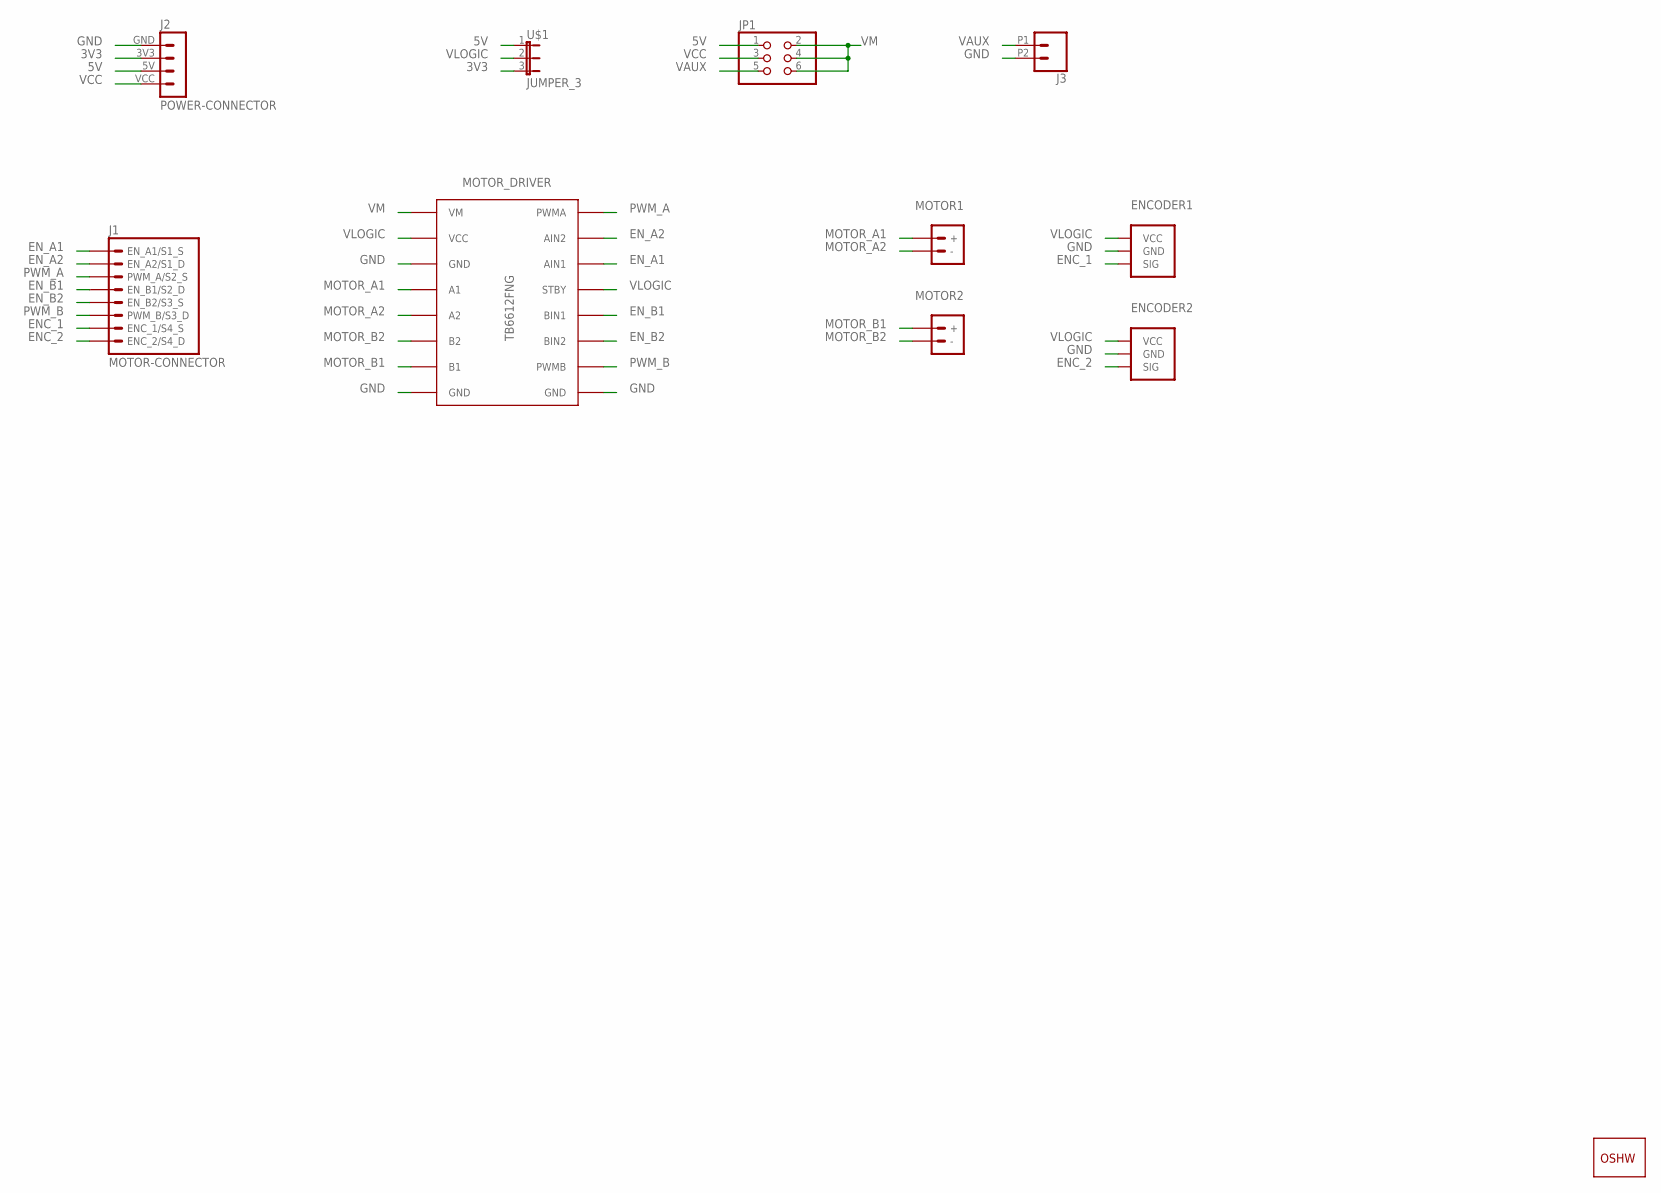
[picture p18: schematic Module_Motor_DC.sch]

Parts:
ENCODER1, ENCODER2: ENCODER/OCT; ENCODER
GOLD_ORB_SM1: OSHWLOGO_GOLD_ORB_MED; OSHW1
J1: MOTOR-CONNECTOR
J2: POWER-CONNECTOR
J3: CONN_022.54MM_SCREWTERM; 1X02_2.54_SCREWTERM
JP1: JUMPER_3X2/OCT; JUMPER_3X2
MOTOR1, MOTOR2: MOTOR-TERMINAL5MM; SCREWTERMINAL-5MM-2
MOTOR_DRIVER: TB6612FNG
U$1: JUMPER_3

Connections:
3V3: J2.3V3, U$1.3
5V: J2.5V, JP1.1, U$1.1
ENC_1: ENCODER1.SIG, J1.ENC_1/S4_S
ENC_2: ENCODER2.SIG, J1.ENC_2/S4_D
EN_A1: J1.EN_A1/S1_S, MOTOR_DRIVER.AIN1
EN_A2: J1.EN_A2/S1_D, MOTOR_DRIVER.AIN2
EN_B1: J1.EN_B1/S2_D, MOTOR_DRIVER.BIN1
EN_B2: J1.EN_B2/S3_S, MOTOR_DRIVER.BIN2
GND: ENCODER1.GND, ENCODER2.GND, J2.GND, J3.P2 (2), MOTOR_DRIVER.GND1 (GND), MOTOR_DRIVER.GND2 (GND), MOTOR_DRIVER.GND3 (GND)
MOTOR_A1: MOTOR1.+, MOTOR_DRIVER.A1
MOTOR_A2: MOTOR1.-, MOTOR_DRIVER.A2
MOTOR_B1: MOTOR2.+, MOTOR_DRIVER.B1
MOTOR_B2: MOTOR2.-, MOTOR_DRIVER.B2
PWM_A: J1.PWM_A/S2_S, MOTOR_DRIVER.PWMA
PWM_B: J1.PWM_B/S3_D, MOTOR_DRIVER.PWMB
VAUX: J3.P1 (1), JP1.5
VCC: J2.VCC, JP1.3
VLOGIC: ENCODER1.VCC, ENCODER2.VCC, MOTOR_DRIVER.STBY, MOTOR_DRIVER.VCC, U$1.2
VM: JP1.2, JP1.4, JP1.6, MOTOR_DRIVER.VM

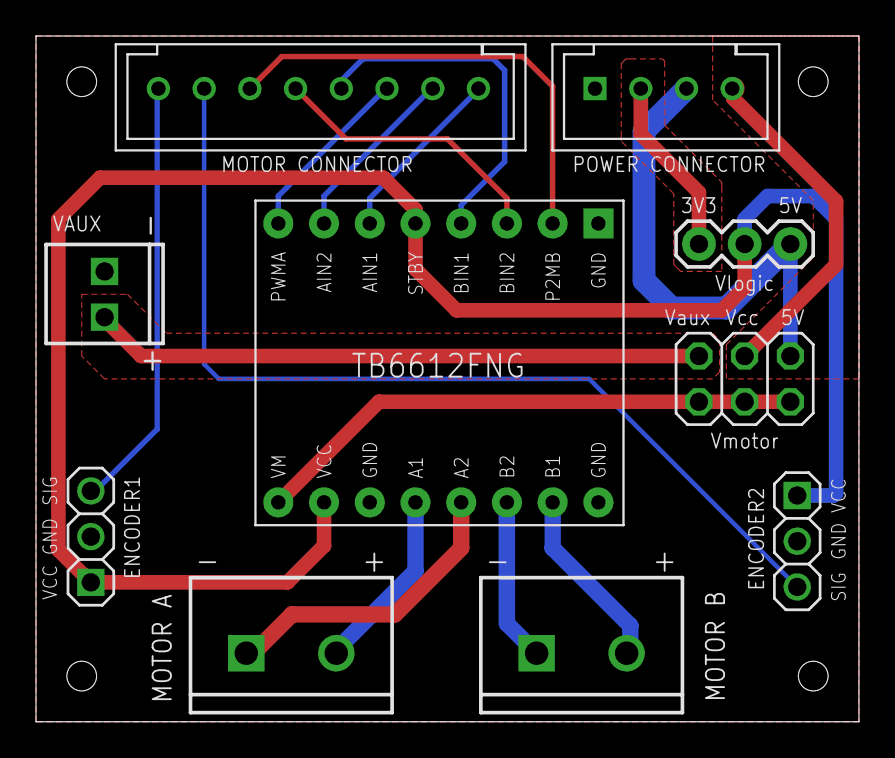
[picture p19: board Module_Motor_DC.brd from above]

Board: 2 copper layers, 45.7 x 38.1 mm, 11 parts (1 on the bottom side), 19 nets.

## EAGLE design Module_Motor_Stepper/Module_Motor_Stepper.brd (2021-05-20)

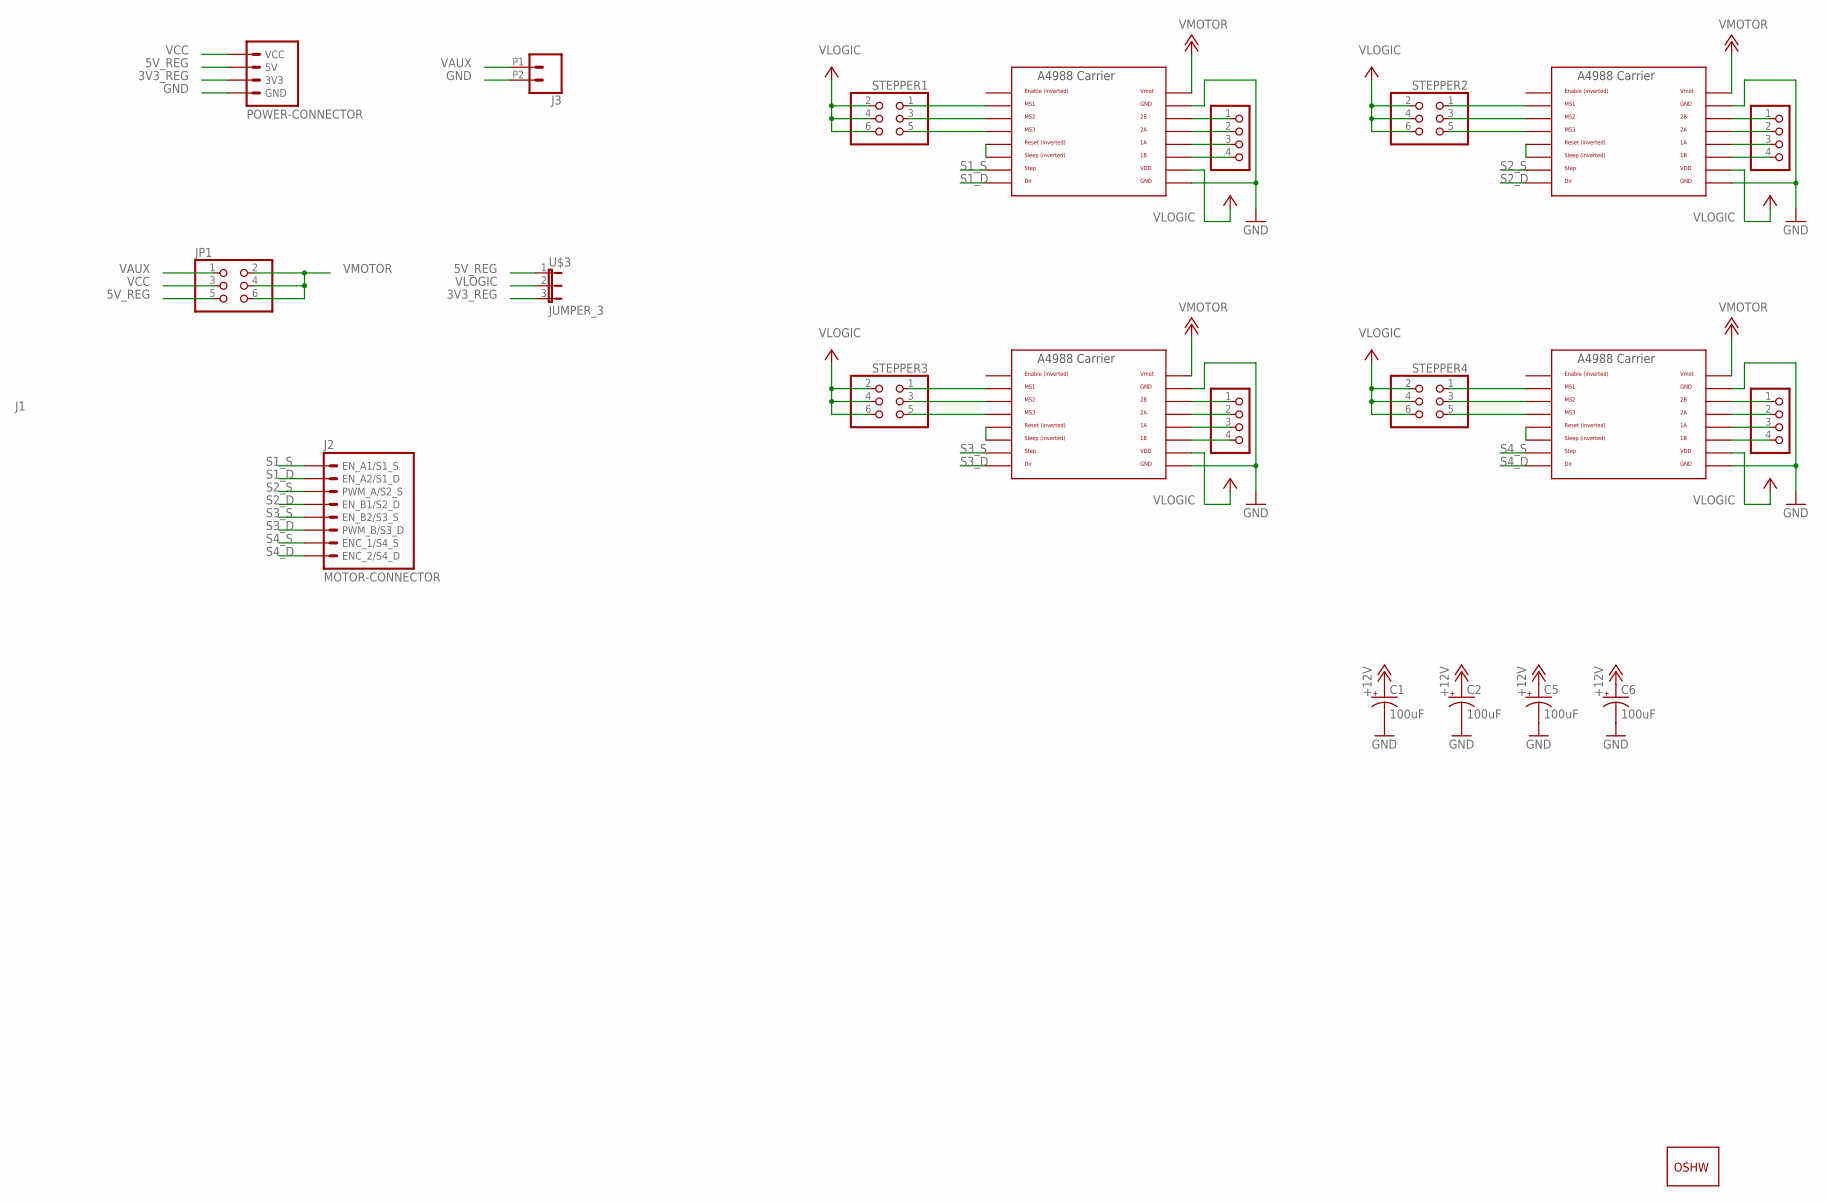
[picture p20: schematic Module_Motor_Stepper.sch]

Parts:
C1, C2, C5, C6: 100uF; 153CLV-0605
E0-MOT1, E0-MOT2, E0-MOT4, E0-MOT6: PINHD-1X4; 1X04
GOLD_ORB_SM1: OSHWLOGO_GOLD_ORB_MED; OSHW1
J1: POWER-CONNECTOR
J2: MOTOR-CONNECTOR
J3: CONN_022.54MM_SCREWTERM; 1X02_2.54_SCREWTERM
JP1: JUMPER_3X2/OCT; JUMPER_3X2
STEPPER1, STEPPER2, STEPPER3, STEPPER4: PINHD-2X3; 2X03
U$1, U$2, U$5, U$7: A4988BREAKOUT
U$3: JUMPER_3

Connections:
3V3_REG: J1.3V3, U$3.3
5V_REG: J1.5V, JP1.5, U$3.1
GND: C1.-, C2.-, C5.-, C6.-, J1.GND, J3.P2 (2), U$1.GND, U$1.GND@0 (GND), U$2.GND, U$2.GND@0 (GND), U$5.GND, U$5.GND@0 (GND), U$7.GND, U$7.GND@0 (GND)
unnamed: STEPPER1.5, U$1.MS3
unnamed: U$1.RST, U$1.SLP (SLEEP)
unnamed: STEPPER1.1, U$1.MS1
unnamed: STEPPER1.3, U$1.MS2
unnamed: E0-MOT1.1, U$1.2B
unnamed: E0-MOT1.2, U$1.2A
unnamed: E0-MOT1.3, U$1.1A
unnamed: E0-MOT1.4, U$1.1B
unnamed: STEPPER2.5, U$2.MS3
unnamed: U$2.RST, U$2.SLP (SLEEP)
unnamed: STEPPER2.1, U$2.MS1
unnamed: STEPPER2.3, U$2.MS2
unnamed: E0-MOT2.1, U$2.2B
unnamed: E0-MOT2.2, U$2.2A
unnamed: E0-MOT2.3, U$2.1A
unnamed: E0-MOT2.4, U$2.1B
unnamed: STEPPER3.5, U$5.MS3
unnamed: U$5.RST, U$5.SLP (SLEEP)
unnamed: STEPPER3.1, U$5.MS1
unnamed: STEPPER3.3, U$5.MS2
unnamed: E0-MOT4.1, U$5.2B
unnamed: E0-MOT4.2, U$5.2A
unnamed: E0-MOT4.3, U$5.1A
unnamed: E0-MOT4.4, U$5.1B
unnamed: STEPPER4.5, U$7.MS3
unnamed: U$7.RST, U$7.SLP (SLEEP)
unnamed: STEPPER4.1, U$7.MS1
unnamed: STEPPER4.3, U$7.MS2
unnamed: E0-MOT6.1, U$7.2B
unnamed: E0-MOT6.2, U$7.2A
unnamed: E0-MOT6.3, U$7.1A
unnamed: E0-MOT6.4, U$7.1B
S1_D: J2.EN_A2/S1_D, U$1.DIR
S1_S: J2.EN_A1/S1_S, U$1.STEP
S2_D: J2.EN_B1/S2_D, U$2.DIR
S2_S: J2.PWM_A/S2_S, U$2.STEP
S3_D: J2.PWM_B/S3_D, U$5.DIR
S3_S: J2.EN_B2/S3_S, U$5.STEP
S4_D: J2.ENC_2/S4_D, U$7.DIR
S4_S: J2.ENC_1/S4_S, U$7.STEP
VAUX: J3.P1 (1), JP1.1
VCC: J1.VCC, JP1.3
VLOGIC: STEPPER1.2, STEPPER1.4, STEPPER1.6, STEPPER2.2, STEPPER2.4, STEPPER2.6, STEPPER3.2, STEPPER3.4, STEPPER3.6, STEPPER4.2, STEPPER4.4, STEPPER4.6, U$1.VDD, U$2.VDD, U$3.2, U$5.VDD, U$7.VDD
VMOTOR: C1.+, C2.+, C5.+, C6.+, JP1.2, JP1.4, JP1.6, U$1.VMOT, U$2.VMOT, U$5.VMOT, U$7.VMOT

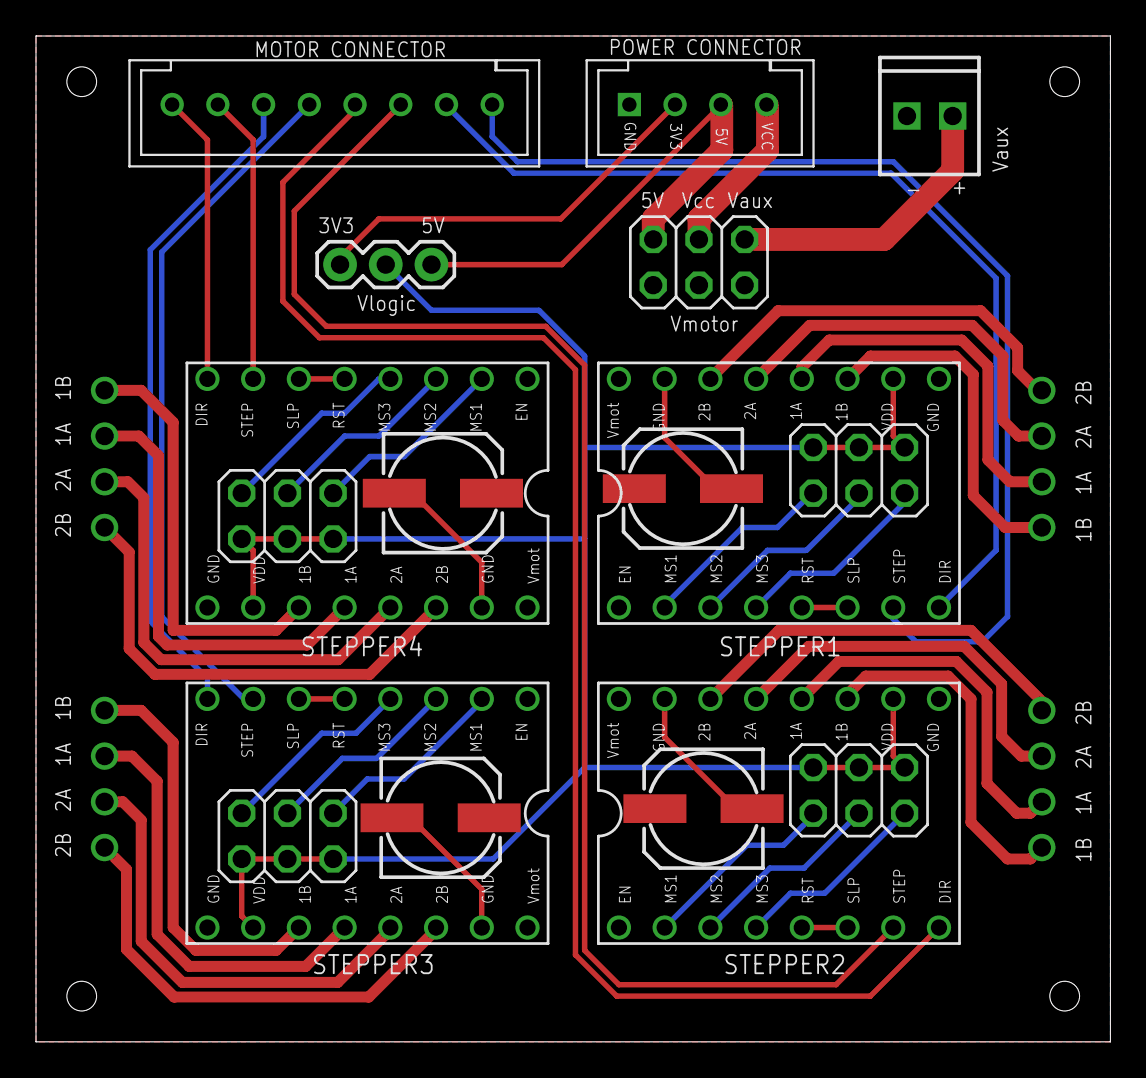
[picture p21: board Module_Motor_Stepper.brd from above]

Board: 2 copper layers, 59.7 x 55.9 mm, 22 parts (1 on the bottom side), 47 nets.

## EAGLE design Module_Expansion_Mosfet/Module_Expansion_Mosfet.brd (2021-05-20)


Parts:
D1, D2, D3: DIODESOD-123; SOD-123
GOLD_ORB_SM1: OSHWLOGO_GOLD_ORB_MED; OSHW1
J1: POWER-TERMINAL2.54MM_SCREWTERM; 1X02_2.54_SCREWTERM
J8, J10, J12: CONN_02LOCK_LONGPADS; 1X02_LOCK_LONGPADS
JP1: JUMPER_3X2/OCT; JUMPER_3X2
MOSFET1, MOSFET2, MOSFET3: AO3404A; SOT23-3
R9, R13, R17: 10k; 1206
R10, R14, R18: 100k; 1206
U$1: CONNECTOR_AUX

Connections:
5V: JP1.3, U$1.5V
GND: J1.-, MOSFET1.2 (S), MOSFET2.2 (S), MOSFET3.2 (S), R10.2, R14.2, R18.2, U$1.GND
IO1: R17.1, R18.1, U$1.GPIO1
IO2: R13.1, R14.1, U$1.GPIO2
IO3: R9.1, R10.1, U$1.GPIO3
unnamed: MOSFET3.1 (G), R9.2
unnamed: D3.A, J8.2, MOSFET3.3 (D)
unnamed: MOSFET2.1 (G), R13.2
unnamed: D1.A, J10.2, MOSFET2.3 (D)
unnamed: MOSFET1.1 (G), R17.2
unnamed: D2.A, J12.2, MOSFET1.3 (D)
VAUX: J1.+, JP1.5
VCC: JP1.1, U$1.VC
VMOSFET: D1.C, D2.C, D3.C, J8.1, J10.1, J12.1, JP1.2, JP1.4, JP1.6


Board: 2 copper layers, 27.9 x 40.6 mm, 19 parts (1 on the bottom side), 14 nets.

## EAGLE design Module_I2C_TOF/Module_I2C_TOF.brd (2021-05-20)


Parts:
CON_I2C_1, CON_I2C_2: CONNECTOR_I2C
GOLD_ORB_SM1: OSHWLOGO_GOLD_ORB_MED; OSHW1
LED2: LEDCHIP-LED0805; CHIP-LED0805
R1, R2: 4.7K; R0805
R3: 1K; R0805
TOF0, TOF1, TOF2, TOF3, TOF4, TOF5, TOF6, TOF7: RANGING-SENSOR-VL53L0X
U$9: I2C-EXPANDER-TCA9548A
U$10: JUMPER_3

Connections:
3V3: CON_I2C_1.3V3, CON_I2C_2.3V3, U$10.3
5V: CON_I2C_1.5V, CON_I2C_2.5V, U$10.1
GND: CON_I2C_1.GND, CON_I2C_2.GND, LED2.C, TOF0.GND, TOF1.GND, TOF2.GND, TOF3.GND, TOF4.GND, TOF5.GND, TOF6.GND, TOF7.GND, U$9.GND
unnamed: LED2.A, R3.1
SC0: TOF7.SCL, U$9.SC0
SC1: TOF0.SCL, U$9.SC1
SC2: TOF1.SCL, U$9.SC2
SC3: TOF2.SCL, U$9.SC3
SC4: TOF3.SCL, U$9.SC4
SC5: TOF4.SCL, U$9.SC5
SC6: TOF5.SCL, U$9.SC6
SC7: TOF6.SCL, U$9.SC7
SCL: CON_I2C_1.SCL, CON_I2C_2.SCL, R2.1, U$9.SCL
SD0: TOF7.SDA, U$9.SD0
SD1: TOF0.SDA, U$9.SD1
SD2: TOF1.SDA, U$9.SD2
SD3: TOF2.SDA, U$9.SD3
SD4: TOF3.SDA, U$9.SD4
SD5: TOF4.SDA, U$9.SD5
SD6: TOF5.SDA, U$9.SD6
SD7: TOF6.SDA, U$9.SD7
SDA: CON_I2C_1.SDA, CON_I2C_2.SDA, R1.1, U$9.SDA
VCC: CON_I2C_1.VC, CON_I2C_2.VC
VIN: R1.2, R2.2, R3.2, TOF0.VIN, TOF1.VIN, TOF2.VIN, TOF3.VIN, TOF4.VIN, TOF5.VIN, TOF6.VIN, TOF7.VIN, U$9.VIN, U$10.2



Board: 2 copper layers, 76.2 x 76.2 mm, 17 parts (3 on the bottom side), 24 nets.

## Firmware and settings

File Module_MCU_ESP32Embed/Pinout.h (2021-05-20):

#pragma once

static const uint8_t UART_TX = 1;
static const uint8_t UART_RX = 3;

static const uint8_t IR1 = 2;
static const uint8_t TOUCH2 = 2;

static const uint8_t SERVO6 = 5;

static const uint8_t TOUCH5 = 12;

static const uint8_t MOTOR1_A = 23;
static const uint8_t STEPPER1_STEP = 23;

static const uint8_t MOTOR1_B = 19;
static const uint8_t STEPPER1_DIR = 19;

static const uint8_t MOTOR1_PWM = 27;
static const uint8_t STEPPER2_STEP = 27;

static const uint8_t MOTOR2_A = 18;
static const uint8_t STEPPER2_DIR = 18;

static const uint8_t MOTOR2_B = 4;
static const uint8_t STEPPER3_STEP = 4;

static const uint8_t MOTOR2_PWM = 13;
static const uint8_t STEPPER3_DIR = 13;

static const uint8_t ENCODER1 = 32;
static const uint8_t STEPPER4_STEP = 32;

static const uint8_t ENCODER2 = 33;
static const uint8_t STEPPER4_DIR = 33;


static const uint8_t SERVO3 = 14;
static const uint8_t TOUCH7 = 14;

static const uint8_t IR_2 = 15;
static const uint8_t TOUCH3 = 15;

static const uint8_t AUX3 = 16;
static const uint8_t SERVO5 = 16;
static const uint8_t SONAR3 = 16;
static const uint8_t UART2_TX = 16;

static const uint8_t SONAR2 = 17;
static const uint8_t SERVO4 = 17;
static const uint8_t UART2_RX = 17;


static const uint8_t I2C_SDA = 21;
static const uint8_t I2C_SCL = 22;

static const uint8_t AUX1 = 25;
static const uint8_t DAC_1 = 25;
static const uint8_t SERVO1 = 25;
static const uint8_t SONAR1 = 25;

static const uint8_t AUX2 = 26;
static const uint8_t DAC_2 = 26;
static const uint8_t SERVO2 = 26;

static const uint8_t ANALOG3 = 34;
static const uint8_t IR3 = 34;

static const uint8_t BAT_SENSE = 35;

static const uint8_t ANALOG1 = 36;
static const uint8_t IR4 = 36;

static const uint8_t ANALOG2 = 39;
static const uint8_t IR5 = 39;

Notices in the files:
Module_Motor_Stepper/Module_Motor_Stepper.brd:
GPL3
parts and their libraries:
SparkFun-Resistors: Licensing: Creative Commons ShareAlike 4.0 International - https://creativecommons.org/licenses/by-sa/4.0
